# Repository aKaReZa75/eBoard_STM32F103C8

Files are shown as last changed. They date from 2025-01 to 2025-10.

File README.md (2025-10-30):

# STM32F103C8T6 Microcontroller

This repository involves designing, assembling, and testing an educational header board for the STM32F103C8 microcontroller, compatible with the Arduino UNO.

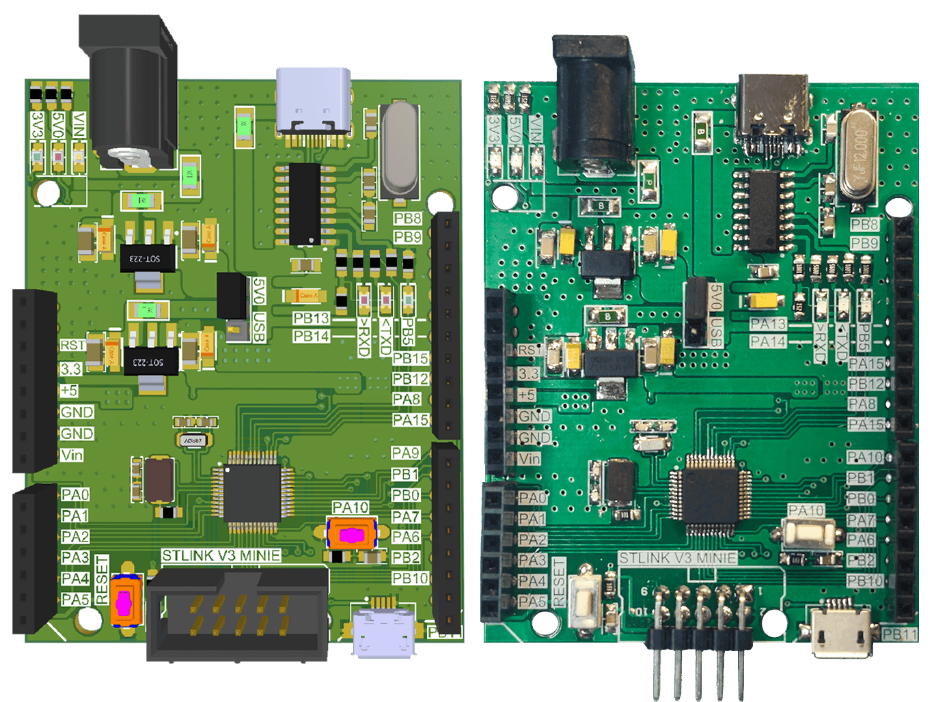
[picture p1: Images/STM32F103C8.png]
STM32F103C8 Shield


> [!IMPORTANT]
> Before sending the board files for PCB fabrication, **always make sure you are using the latest released version** of the project.
> Hardware issues or design flaws might exist in earlier versions and could be fixed in newer releases.
> To avoid costly mistakes and ensure the best performance, always refer to the **[Releases](../../releases)** section, where all known issues, updates, and version-specific notes are clearly documented.

## STM32F103C8T6 Pin Mapping Table 
| **Arduino Pin** | **STM32F103C8 Pin** | **Functionality** |
| :---: | :---: | :--- |
| A0 | PA0 | ADC-IN0 |
| A1 | PA1 | ADC-IN1 |
| A2 | PA2 | ADC-IN2 |
| A3 | PA3 | ADC-IN3 |
| A4 | PA4 | ADC-IN4 |
| A5 | PA5 | ADC-IN5 |
| D0 | PB11 | UART3-RX |
| D1 | PB10 | UART3-TX |
| D2 | PB2 | GPIO |
| D3 | PA6 | TIM3-CH1 PWM |
| D4 | PA7 | TIM3-CH2 PWM |
| D5 | PB0 | TIM3-CH3 PWM |
| D6 | PB1 | TIM3-CH4 PWM |
| D7 | PA9 | GPIO |
| D8 | PA15 | TIM2-CH1 ICP |
| D9 | PA8 | TIM1-CH1 PWM |
| D10 | PB12 | SPI2 (NSS) |
| D11 | PB15 | SPI2 (MOSI) |
| D12 | PB14 | SPI2 (MISO) |
| D13 | PB13 | SPI2 (SCK) |
| SDA | PB9 | I2C1 (SDA) |
| SCL | PB8 | I2C1 (SCL) |
| LED | PB5 | Built-in LED |
| KEY | PA10 | Built-in Key |
| CH340-RX | PB6 | UART1-TX (CH340)  |
| CH340-TX | PB7 | UART1-RX (CH340)  |

### **ADC (Analog-to-Digital Converter)**
| **Arduino Pin** | **STM32 Pin** | **ADC Channel** | 
| --- | --- | --- |
| A0 | PA0 | ADC_IN0 | 
| A1 | PA1 | ADC_IN1 | 
| A2 | PA2 | ADC_IN2 | 
| A3 | PA3 | ADC_IN3 | 
| A4 | PA4 | ADC_IN4 | 
| A5 | PA5 | ADC_IN5 | 

### **Timers / PWM Outputs**
| **Arduino Pin** | **STM32 Pin** | **PWM / Timer** |
| --- | --- | --- |
| D3 | PA6 | TIM3_CH1 (PWM)  |
| D4 | PA7 | TIM3_CH2 (PWM)  |
| D5 | PB0 | TIM3_CH3 (PWM)  |
| D6 | PB1 | TIM3_CH4 (PWM)  |
| D9 | PA8 | TIM1_CH1 (PWM)  |

| **Arduino Pin** | **STM32 Pin** | **Special Timer Function** |
| --- | --- | --- |
| D8 | PA15 | TIM2_CH1 (Input Capture) |

### **USART (Serial Communication)**
| **Function** | **Arduino Pin** | **STM32 Pin** | **USART Function** |
| --- | --- | --- | --- |
| UART3 RX | D0 | PB11 | USART3_RX |
| UART3 TX | D1 | PB10 | USART3_TX |
| CH340 RX (USB) | CH340-RX | PB6 | USART1_TX |
| CH340 TX (USB) | CH340-TX | PB7 | USART1_RX |

### **I2C Interface**
| **Arduino Pin** | **STM32 Pin** | **I2C Signal** |
| --- | --- | --- |
| SDA | PB9 | I2C1_SDA |
| SCL | PB8 | I2C1_SCL |

### **SPI Interface**
| **Arduino Pin** | **STM32 Pin** | **SPI Signal** |
| --- | --- | --- |
| D10 | PB12 | SPI2_NSS |
| D11 | PB15 | SPI2_MOSI |
| D12 | PB14 | SPI2_MISO |
| D13 | PB13 | SPI2_SCK |

### **Other / General Purpose**
| **Arduino Pin** | **STM32 Pin** | **Functionality** |
| --- | --- | --- |
| LED | PB5 | Onboard LED |
| KEY | PA10 | User Key |
| D2 | PB2 | GPIO/eInt |
| D7 | PA9 | GPIO/TIM1_CH2 |

---

<table>
  <tr>
  <td valign="top">
  
  > [!TIP]  
  > If you're looking to better understand how to navigate and use my GitHub repositories — including exploring their structure, downloading or cloning projects, submitting issues, and asking questions,  
  > everything you need is clearly explained in this video:  
  > [aKaReZa 95 - Programming, Git - PART B](https://youtu.be/zYiUItVFRqQ)  
  > Make sure to check it out!
  
  </td>
    <td width="360" valign="middle" style="padding: 0;">
      <a href="https://youtu.be/zYiUItVFRqQ">
       aKaReZa 95 - Programming, Git - PART B Thumbnail
      </a>
    </td>
  </td>
  </tr>

<tr>
  <td valign="top">
  
  > [!IMPORTANT]
  > Begin your embedded systems journey with clarity and purpose. This episode outlines a structured roadmap for mastering microcontrollers, communication protocols, hardware design, and project development.  
  > Learn how to choose your specialization, follow curated playlists, and engage effectively with the community—ideal for learners seeking a scalable, goal-driven path into embedded engineering.  
  > [aKaReZa 124 – Embedded Systems Roadmap](https://youtu.be/3QYfv7A7aMc)  
  > Watch it now to kickstart your journey!
  
  </td>
  <td width="360" valign="middle" style="padding: 0;">
    <a href="https://youtu.be/3QYfv7A7aMc">
      aKaReZa 124 – Embedded Systems Roadmap Thumbnail
    </a>
  </td>
</tr>

  <tr>
  <td colspan="3">

  > [!CAUTION]
  > It is absolutely critical that you carefully read every single word of this document, line by line, to ensure you don't miss any details. Nothing can be overlooked.
      
  </td>
  </tr>  
</table>

## Key Features
- **Core**: ARM Cortex-M3 32-bit RISC core.
- **Clock Speed**: Up to 72 MHz.
- **Flash Memory**: 64 KB of flash memory for program storage.
- **SRAM**: 20 KB of static RAM.
- **GPIO Pins**: 37 general-purpose I/O pins.
- **Communication Interfaces**:
  - **USART**: Up to 3 universal synchronous/asynchronous receivers/transmitters.
  - **SPI**: Up to 2 Serial Peripheral Interfaces.
  - **I2C**: Up to 2 Inter-Integrated Circuit interfaces.
  - **USB**: Full-speed USB 2.0 interface.
- **Timers**:
  - **Advanced-control Timers**: 1 x 16-bit.
  - **General-purpose Timers**: 3 x 16-bit.
  - **SysTick Timer**: 24-bit down counter.
- **ADC**: 2 x 12-bit Analog-to-Digital Converters with up to 10 channels.
- **DAC**: 2 x 12-bit Digital-to-Analog Converters.
- **DMA**: 7-channel Direct Memory Access controller.
- **Operating Voltage**: 2.0V to 3.6V.
- **Power Consumption**: Low-power modes for energy-efficient applications.

## Capabilities
- **High Performance**: ARM Cortex-M3 core delivers high efficiency and performance.
- **Rich Peripherals**: Integrated peripherals like USB, ADC, DAC, and timers make it suitable for complex applications.
- **Flexibility**: Supports a wide range of applications, from simple control systems to advanced IoT devices.
- **Ease of Development**: Extensive support from STM32CubeMX, HAL libraries, and third-party tools like ST-Link.
- **Community Support**: Large community and extensive documentation available.

## Applications
- **Embedded Systems**: Used in various embedded applications due to its robustness and flexibility.
- **IoT Devices**: Ideal for IoT applications with its low power consumption and communication interfaces.
- **Industrial Automation**: Suitable for industrial control systems and automation.
- **Consumer Electronics**: Found in various consumer electronic devices.
- **Robotics**: Commonly used in robotics for motor control and sensor interfacing.

## Development Tools
- **IDEs**: Keil MDK.
- **Programmers**: STLINK-V3MINIE.
- **Debuggers**: STLINK-V3MINIE, Serial debugging via UART, print (using SWO).

## Detailed Description
| Aspect | Description |
|---|---|
| PCB Design Software  | Altium  V24.2.2 |
| PCB Layers | 2-Layer FR4 |
| Microcontroller | STM32F103C8 |
| Pin Type | Arduino UNO |
| Converter IC | CH340 |
| USB Port | TYPE-C |

# 🔗 Resources
  Here you'll find a collection of useful links and documents related to the STM32 microcontroller and its applications.   
  These resources include datasheets, tutorials, and essential tools to get you started and guide you through.

> [!TIP]
> The resources are detailed in the sections below.  
> To access any of them, simply click on the corresponding blue link.

- [Altium Library](https://github.com/aKaReZa75/Altium-Library)  
  ---  
   All PCB designs across all repositories and projects are built using this Altium Designer component library. It contains a wide range of verified footprints, schematic symbols, and 3D models, ensuring consistency and accuracy in PCB designs. If you're working on a new PCB, using this library will save you time and minimize errors.

- [PCB & Electronics Design Training](https://github.com/aKaReZa75/PCB)  
  ---  
  This repository is dedicated to **learning PCB design and electronics from scratch**. It covers everything from circuit theory to practical PCB layout techniques, including routing strategies, best practices, and component placement. Whether you're a beginner or an experienced designer, this resource will help you **improve your PCB design skills and create professional-quality boards**.

- [Microcontroller Training](https://github.com/aKaReZa75/Microcontroller)  
  ---  
  This repository offers a comprehensive guide to learning **various microcontrollers** and how to interface them with different shields. You’ll find tutorials on **using and configuring shields**, along with hands-on projects to help you **get your microcontrollers up and running**. Whether you're working with **Arduino, STM32, ESP32**, or others, this resource will help you understand how to integrate these platforms effectively for your projects.

- [STM32 Microcontroller Training](https://github.com/aKaReZa75/STM32)  
  ---  
  This repository offers a **comprehensive guide to STM32 microcontroller programming**, focusing on the STM32F103C8T6. Explore **STM32 architecture, peripheral configuration, timers, interrupts, communication protocols (UART, SPI, I2C), and real-time applications** through practical examples and hands-on projects. Whether you're a beginner or an experienced developer, this resource will help you build a strong foundation and advance your skills in STM32 embedded development.

- [Shopping Link](./ShoppingLink.md)  
  ---
  This document provides links to trusted suppliers where you can purchase all the essential components for this project, ensuring quality and reliability.

## Project Videos

```plaintext
Educational Boards
   └── [aKaReZa 107 - eBoard, STM32F103C8]
       ├─ Design Review — Migrating from ATMEGA328 layout.
       ├─ Power Setup — Pin connections and safety.
       ├─ Oscillators — HSE and LSE integration.
       ├─ Boot Config — Pin modes and selection.
       ├─ Programmer — STLINK connection and setup.
       ├─ I/O Mapping — Practical pin assignments.
       └─ PCB Layout — Placement strategies for routing.
```

<table style="border-collapse: collapse;">
  <tr>
    <td valign="top" style="padding: 0 10px;">
      <h3 style="margin: 0;">
        <a href="https://youtu.be/Mtyp9QHlwoI">aKaReZa 107 – eBoard, STM32F103C8</a>
      </h3>
      <p style="margin: 8px 0 0;">
        Step-by-step guide to designing an educational STM32F103C8 board, covering power supply, oscillator setup, boot pin configurations, STLINK connection, I/O mapping, and PCB layout tips—ideal for mastering STM32 hardware design through hands-on learning.
      </p>
    </td>
    <td width="360" valign="top">
      <a href="https://youtu.be/Mtyp9QHlwoI">
        aKaReZa 107 – eBoard, STM32F103C8 Thumbnail
      </a>
    </td>
  </tr>

  <tr>
    <td valign="top" style="padding: 0 10px;">
      <h3 style="margin: 0;">
        <a href="https://youtu.be/Qt_0GZEKY6k">aKaReZa 111 – Repair, STM32F103C8 Soldering</a>
      </h3>
      <p style="margin: 8px 0 0;">
        Follow the complete soldering guide for the STM32F103C8 educational board, including power input setup, voltage regulator testing, microcontroller soldering, USB communication via CH340, THT connector mounting, and final board verification.
      </p>
    </td>
    <td width="360" valign="top">
      <a href="https://youtu.be/Qt_0GZEKY6k">
        aKaReZa 111 – Repair, STM32F103C8 Soldering Thumbnail
      </a>
    </td>
  </tr>
  
</table>

# 💻 How to Use Git and GitHub
To access the repository files and save them on your computer, there are two methods available:
1. **Using Git Bash and Cloning the Repository**
   - This method is more suitable for advanced users and those familiar with command-line tools.
   - By using this method, you can easily receive updates for the repository.

2. **Downloading the Repository as a ZIP file**
   - This method is simpler and suitable for users who are not comfortable with command-line tools.
   - Note that with this method, you will not automatically receive updates for the repository and will need to manually download any new updates.

## Clone using the URL.
First, open **Git Bash** :
-  Open the folder in **File Explorer** where you want the library to be stored.
-  **Right-click** inside the folder and select the option **"Open Git Bash here"** to open **Git Bash** in that directory.

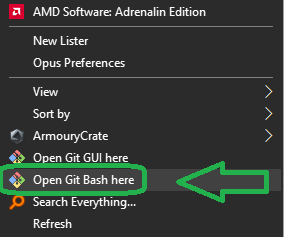
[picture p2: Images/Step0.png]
open Git Bash


> [!NOTE] 
> If you do not see the "Open Git Bash here" option, it means that Git is not installed on your system.  
> You can download and install Git from [this link](https://git-scm.com/downloads).  
> For a tutorial on how to install and use Git, check out [this video](https://youtu.be/BsykgHpmUt8).
  
-  Once **Git Bash** is open, run the following command to clone the repository:

 ```bash
git clone https://github.com/aKaReZa75/eBoard_STM32F103C8.git
```
- You can copy the above command by either:
- Clicking on the **Copy** button on the right of the command.
- Or select the command text manually and press **Ctrl + C** to copy.
- To paste the command into your **Git Bash** terminal, use **Shift + Insert**.

Clone the Repository

- Then, press Enter to start the cloning operation and wait for the success message to appear.

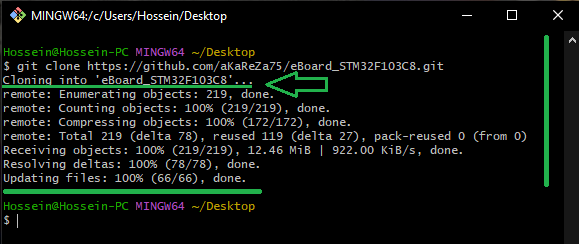
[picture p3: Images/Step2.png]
Open the Library File


> [!IMPORTANT]
> Please keep in mind that the numbers displayed in the image might vary when you perform the same actions.  
> This is because repositories are continuously being updated and expanded. Nevertheless, the overall process remains unchanged.

> [!NOTE]
> Advantage of Cloning the Repository:  
> - **Receiving Updates:** By cloning the repository, you can easily and automatically receive new updates.  
> - **Version Control:** Using Git allows you to track changes and revert to previous versions.  
> - **Team Collaboration:** If you are working on a project with a team, you can easily sync changes from team members and collaborate more efficiently.  

## Download Zip
If you prefer not to use Git Bash or the command line, you can download the repository directly from GitHub as a ZIP file.  
Follow these steps:  
1. Navigate to the GitHub repository page and Locate the Code button:
   - On the main page of the repository, you will see a green Code button near the top right corner.

2. Download the repository:
   - Click the Code button to open a dropdown menu.
   - Select Download ZIP from the menu.

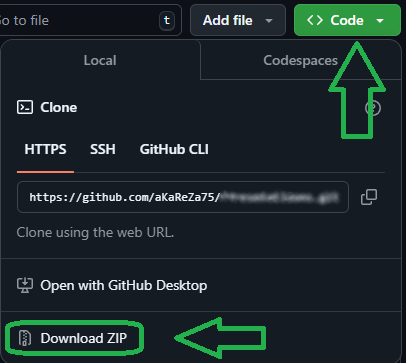
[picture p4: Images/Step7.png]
Download Zip
    

3. Save the ZIP file:
   - Choose a location on your computer to save the ZIP file and click Save.

4. Extract the ZIP file:
   - Navigate to the folder where you saved the ZIP file.
   - Right-click on the ZIP file and select Extract All... (Windows) or use your preferred extraction tool.
   - Choose a destination folder and extract the contents.

5. Access the repository:
   - Once extracted, you can access the repository files in the destination folder.

> [!IMPORTANT]
> - No Updates: Keep in mind that downloading the repository as a ZIP file does not allow you to receive updates.    
>   If the repository is updated, you will need to download it again manually.  
> - Ease of Use: This method is simpler and suitable for users who are not comfortable with Git or command-line tools.

# 📝 How to Ask Questions
If you have any questions or issues, you can raise them through the **"Issues"** section of this repository. Here's how you can do it:  

1. Navigate to the **"Issues"** tab at the top of the repository page.  

  Issues

2. Click on the **"New Issue"** button.  
   
  New Issue

3. In the **Title** field, write a short summary of your issue or question.  

4. In the "Description" field, detail your question or issue as thoroughly as possible. You can use text formatting, attach files, and assign the issue to someone if needed. You can also use text formatting (like bullet points or code snippets) for better readability.  

5. Optionally, you can add **labels**, **type**, **projects**, or **milestones** to your issue for better categorization.  

6. Click on the **"Submit new issue"** button to post your question or issue.
   
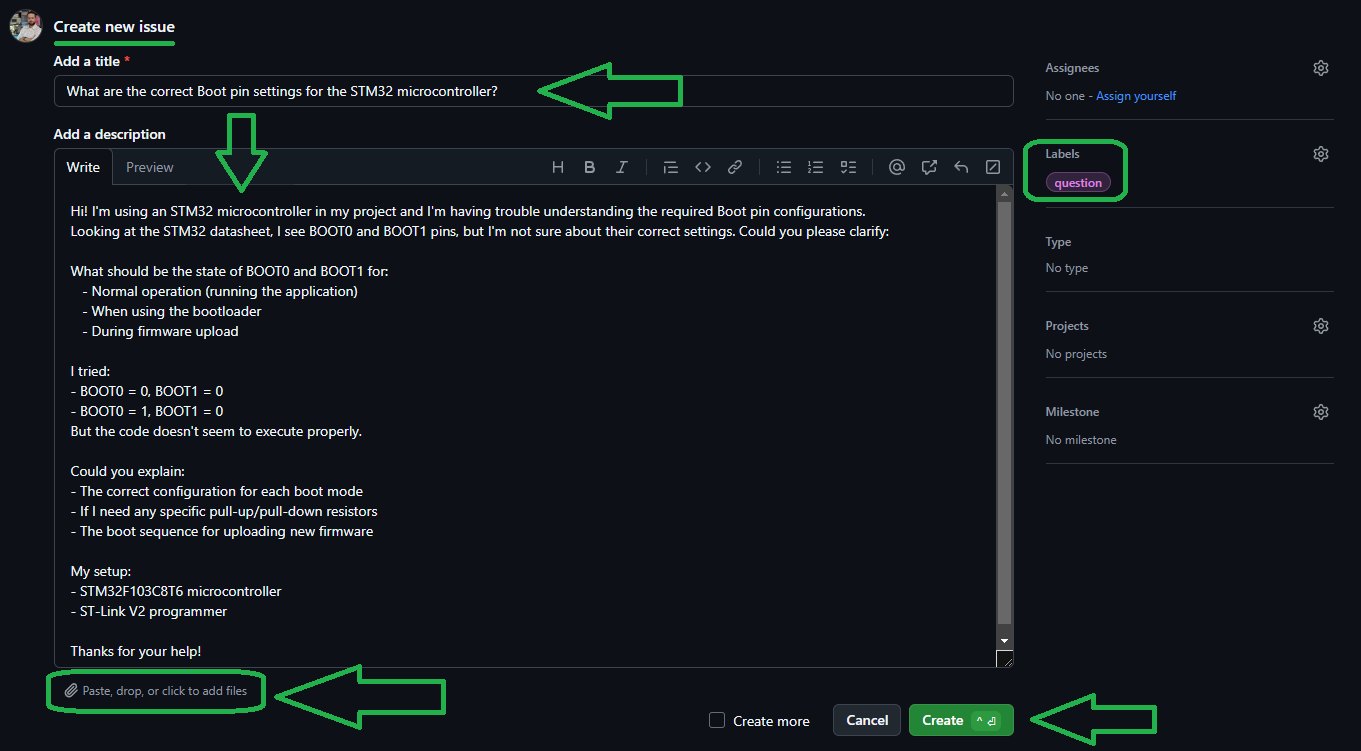
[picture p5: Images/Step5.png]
Submeet New Issue
  

I will review and respond to your issue as soon as possible. Your participation helps improve the repository for everyone!  

> [!TIP]
> - Before creating a new issue, please check the **"Closed"** section to see if your question has already been answered.  
>   Closed section  
> - Write your question clearly and respectfully to ensure a faster and better response.  
> - While the examples provided above are in English, feel free to ask your questions in **Persian (فارسی)** as well.  
> - There is no difference in how they will be handled!  

> [!NOTE]
> Pages and interfaces may change over time, but the steps to create an issue generally remain the same.

# 🤝 Contributing to the Repository
To contribute to this repository, please follow these steps:
1. **Fork the Repository**  
2. **Clone the Forked Repository**  
3. **Create a New Branch**  
4. **Make Your Changes**  
5. **Commit Your Changes**  
6. **Push Your Changes to Your Forked Repository**  
7. **Submit a Pull Request (PR)**  

> [!NOTE]
> Please ensure your pull request includes a clear description of the changes you’ve made.
> Once submitted, I will review your contribution and provide feedback if necessary.

# 🌟 Support Me
If you found this repository useful:
- Subscribe to my [YouTube Channel](https://www.youtube.com/@aKaReZa75).
- Share this repository with others.
- Give this repository and my other repositories a star.
- Follow my [GitHub account](https://github.com/aKaReZa75).

# 📜 License
This project is licensed under the GPL-3.0 License. This license grants you the freedom to use, modify, and distribute the project as long as you:
- Credit the original authors: Give proper attribution to the original creators.
- Disclose source code: If you distribute a modified version, you must make the source code available under the same GPL license.
- Maintain the same license: When you distribute derivative works, they must be licensed under the GPL-3.0 too.
- Feel free to use it in your projects, but make sure to comply with the terms of this license.
  
# ✉️ Contact Me
Feel free to reach out to me through any of the following platforms:
- 📧 [Email: aKaReZa75@gmail.com](mailto:aKaReZa75@gmail.com)
- 🎥 [YouTube: @aKaReZa75](https://www.youtube.com/@aKaReZa75)
- 💼 [LinkedIn: @akareza75](https://www.linkedin.com/in/akareza75)

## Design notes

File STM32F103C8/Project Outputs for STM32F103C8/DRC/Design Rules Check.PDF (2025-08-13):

### Design Rules Verification Report

Filename : E:\aKaReZa\#gitHub\eBoard_STM32F103C8\STM32F103C8\PCB.PcbDoc | Warnings 0

### Rule Violations 0 Waived Violations 6

Warnings
Total | 0

Rule Violations
Clearance Constraint (Gap=0.2mm) (All),(All) | 0
Clearance Constraint (Gap=0.25mm) (All),(InPolygon) | 0
Short-Circuit Constraint (Allowed=No) (All),(All) | 0
Un-Routed Net Constraint ( (All) ) | 0
Modified Polygon (Allow modified: No), (Allow shelved: No) | 0
Width Constraint (Min=0.2mm) (Max=10mm) (Preferred=0.2mm) (All) | 0
Routing Layers(All) | 0
Routing Via (MinHoleWidth=0.4mm) (MaxHoleWidth=3mm) (PreferredHoleWidth=0.4mm) (MinWidth=0.7mm) | 0
Differential Pairs Uncoupled Length using the Gap Constraints (Min=0.254mm) (Max=0.254mm) (Prefered=0.254mm) | 0
Power Plane Connect Rule(Relief Connect )(Expansion=0.508mm) (Conductor Width=0.254mm) (Air Gap=0.254mm) | 0
Minimum Annular Ring (Minimum=0.15mm) (All) | 0
Acute Angle Constraint [Tracks Only] (Minimum=60.000) (All) | 0
Hole Size Constraint (Min=0.4mm) (Max=10mm) (All) | 0
Hole To Hole Clearance (Gap=0.3mm) (All),(All) | 0
Minimum Solder Mask Sliver (Gap=0.01mm) (All),(All) | 0
Silk To Solder Mask (Clearance=0.01mm) (IsPad),(All) | 0
Net Antennae (Tolerance=0mm) (All) | 0
Board Clearance Constraint (Gap=0mm) (All) | 0
Height Constraint (Min=0mm) (Max=25.4mm) (Prefered=12.7mm) (All) | 0
Total | 0

Waived Violations
Minimum Annular Ring (Minimum=0.15mm) (All) | 6
Total | 6

Minimum Annular Ring (Minimum=0.15mm) (All)
Minimum Annular Ring: (No Ring) Pad P2-H1(2.667mm,54.737mm) on Multi-Layer (Annular Ring missing on Top Layer)Waived by aKaReZa at
Minimum Annular Ring: (No Ring) Pad P2-H2(7.747mm,2.667mm) on Multi-Layer (Annular Ring missing on Top Layer)Waived by aKaReZa at Minimum Annular Ring: (No Ring) Pad P2-H3(35.687mm,2.667mm) on Multi-Layer (Annular Ring missing on Top Layer)Waived by aKaReZa at Minimum Annular Ring: (No Ring) Pad P2-H4(50.927mm,53.467mm) on Multi-Layer (Annular Ring missing on Top Layer)Waived by aKaReZa at Minimum Annular Ring: (No Ring) Via (41.675mm,3.674mm) from Top Layer to Bottom Layer (Annular Ring missing on Top Layer)Waived by its ok at Minimum Annular Ring: (No Ring) Via (45.675mm,3.674mm) from Top Layer to Bottom Layer (Annular Ring missing on Top Layer)Waived by its ok at

Reference point outside the component area: Small Component J2-Female (14.224mm,72.771mm) on Top Layer

Micro-Segment: Region (0 hole(s)) Top Layer P1(16.51mm,51.689mm) P2(16.51mm,51.689mm)

Micro-Segment: Region (0 hole(s)) Top Layer P1(16.51mm,49.403mm) P2(16.51mm,49.403mm)

Self-intersection: Region (0 hole(s)) Top Layer (9.273mm,29.045mm)

Wednesday 13 Aug 2025 1:45:30 PM | Page 1 of 1

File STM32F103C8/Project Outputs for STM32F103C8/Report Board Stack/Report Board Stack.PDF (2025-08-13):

# Board Stack Report

Stack Up | Layer Stack
Layer | Board Layer Stack | Name | Material | Thickness Constant Dk | | | Coverlay expansion | Orientation | Copper Orientation
1 | | Top Overlay | | 0mm
2 | | Top Solder | Solder Resist | 0.01016mm | 3.5 | 3.5 0mm
3 | | Top Layer | | 0.03556mm | | | | BodyUp | Above
4 | | Dielectric 1 | FR-4 | 1.5mm | 4.8 | 4.8
5 | | Bottom Layer | | 0.03556mm | | | | BodyDown | Below
6 | | Bottom Solder | Solder Resist | 0.01016mm | 3.5 | 3.5 0mm
7 | | Bottom Overlay | | 0mm
| Height : 1.59144mm

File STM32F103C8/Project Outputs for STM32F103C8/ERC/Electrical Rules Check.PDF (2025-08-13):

### Electrical Rules Check Report

Class | Document | Message Successful Compile for STM32F103C8.PrjPcb
Wednesday 13 Aug 2025 1:45:31 PM | Page 1 of 1

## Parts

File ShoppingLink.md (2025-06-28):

# 📦 Components Purchase Links
This section provides a comprehensive list of components required for the "STM32F103C8 Board" project.
Each item includes direct purchase links from reliable Iranian electronics suppliers, with recommended quantities for both essential needs and future prototyping.

## Capacitor
- [ ] [**Cap_0603_18p**](https://lionelectronic.ir/products/1900-0603CG180J500NT) Quantity: 2, Prefer: 25, Supplier: LionElectronic **(Instead of: Cap_0603_18.5p)**
- [ ] [**Cap_0603_33p**](https://lionelectronic.ir/products/3759-GRM1885C1H330FA01D) Quantity: 2, Prefer: 25, Supplier: LionElectronic
- [ ] [**Cap_0805_22p**](https://lionelectronic.ir/products/1950-TCC0805COG220J500BT) Quantity: 2, Prefer: 25, Supplier: LionElectronic
- [ ] [**Cap_0805_10n**](https://lionelectronic.ir/products/1973-0805B103K500NT) Quantity: 1, Prefer: 25, Supplier: LionElectronic
- [ ] [**Cap_0805_100n**](https://lionelectronic.ir/products/2791-CL21B104KBCNNNC) Quantity: 8, Prefer: 25, Supplier: LionElectronic
- [ ] [**Cap_1206_100n**](https://lionelectronic.ir/products/5156-C3216NP01H104J160AA) Quantity: 4, Prefer: 25, Supplier: LionElectronic
- [ ] [**Cap_Tantal_10u_10V_A**](https://lionelectronic.ir/products/2046-TAJA106K010RNJ) Quantity: 2, Prefer: 10, Supplier: LionElectronic **(Instead of: Cap_Tantal_10u_6.3V_A)**
- [ ] [**Cap_Tantal_10u_16V_A**](https://lionelectronic.ir/products/2047-TAJA106K016RNJ) Quantity: 2, Prefer: 5, Supplier: LionElectronic 
- [ ] [**Cap_Tantal_22u_6.3V_A**](https://lionelectronic.ir/products/2051-TAJA226M006RNJ) Quantity: 2, Prefer: 5, Supplier: LionElectronic 

## Connector
- [ ] [**Power_Jack**](https://lionelectronic.ir/products/4704-DC005) Quantity: 1, Prefer: 10, Supplier: LionElectronic  
- [ ] [**Con_BoxHeadr_2x5**](https://roboeq.ir/products/detail/1504018/%D8%A8%D8%A7%DA%A9%D8%B3-%D9%87%D8%AF%D8%B1-5-2-BOX-HEADER-%D8%B5%D8%A7%D9%81/) Quantity: 1, Prefer: 5, Supplier: RoboEQ  
- [ ] [**Con_IDC_2x5**](https://roboeq.ir/products/detail/1504001/%D8%A2%DB%8C-%D8%AF%DB%8C-%D8%B3%DB%8C-IDC-2-5/) Quantity: 1, Prefer: 5, Supplier: RoboEQ  
- [ ] [**Flat Cable**](https://roboeq.ir/products/detail/1301002/%DA%A9%D8%A7%D8%A8%D9%84-20-%D8%B1%D8%B4%D8%AA%D9%87-%D9%81%D9%84%D8%AA/) Quantity: 0.2, Prefer: 1, Supplier: RoboEQ  
- [ ] [**Male_PinHeader**](https://lionelectronic.ir/products/5356-PLS-2.54-1X40GF) Quantity: 0.1, Prefer: 1, Supplier: LionElectronic  
- [ ] [**Female_PinHeader**](https://lionelectronic.ir/products/5360-PBS-2.54-1X40GF) Quantity: 1, Prefer: 2, Supplier: LionElectronic  
- [ ] [**USB_Type_C_12**](https://ickala.com/usb-onboard/29448-usb-smd-onboard.html) Quantity: 1, Prefer: 2, Supplier: ICkala
- [ ] [**USB_Type_Micro**](https://lionelectronic.ir/products/4129-MicroQTJ) Quantity: 1, Prefer: 2, Supplier: LionElectronic 

## Integrated Circuit
- [ ] [**IC_STM32F103C8**](https://lionelectronic.ir/products/267-STM32F103C8T6) Quantity: 1, Prefer: 3, Supplier: LionElectronic   
- [ ] [**Reg_AMS1117-5**](https://lionelectronic.ir/products/2189-AMS1117-5.0) Quantity: 1, Prefer: 3, Supplier: LionElectronic  
- [ ] [**Reg_AMS1117-3.3**](https://lionelectronic.ir/products/868-AMS1117-3.3) Quantity: 1, Prefer: 3, Supplier: LionElectronic  
- [ ] [**IC_CH340G**](https://lionelectronic.ir/products/3547-CH340G) Quantity: 1, Prefer: 2, Supplier: LionElectronic  

## Inductor
- [ ] [**Ind_0805_100u**](https://lionelectronic.ir/products/2146-EBLS201212-101K) Quantity: 1, Prefer: 5, Supplier: LionElectronic

## Other
- [ ] [**Fuse_1206_0.5A**](https://lionelectronic.ir/products/1891-JFC1206-0500FS-63V-0.5A) Quantity: 3, Prefer: 10, Supplier: LionElectronic  
- [ ] [**Fuse_1206_3A**](https://lionelectronic.ir/products/1894-JFC1206-1300FS-63V-3A) Quantity: 1, Prefer: 5, Supplier: LionElectronic
- [ ] [**Crystal 32.768KHz**](https://lionelectronic.ir/products/4290-XKXGI-SUA-32.768K) Quantity: 1, Prefer: 5, Supplier: LionElectronic
- [ ] [**Crystal 8MHz**](https://lionelectronic.ir/products/2158-XTAL-8MHZ%28YSX530GA%29) Quantity: 1, Prefer: 5, Supplier: LionElectronic
- [ ] [**Crystal 12MHz**](https://lionelectronic.ir/products/2096-XTAL-12MHZ%28HC-49SMD%29) Quantity: 1, Prefer: 5, Supplier: LionElectronic
- [ ] [**Jumper**](https://ickala.com/pin-header-jumper/26295-jumper2pin-%D9%82%D8%B1%D9%85%D8%B2.html) Quantity: 1, Prefer: 10, Supplier: ICKala

## Resistor
- [ ] [**Res_0805_0b**](https://lionelectronic.ir/products/1536-SER0805J0R) Quantity: 2, Prefer: 25, Supplier: LionElectronic
- [ ] [**Res_0805_220b**](https://lionelectronic.ir/products/1565-SER0805J220R) Quantity: 1, Prefer: 25, Supplier: LionElectronic  
- [ ] [**Res_0805_390b**](https://lionelectronic.ir/products/1416-0805W8F3900T5E) Quantity: 1, Prefer: 25, Supplier: LionElectronic
- [ ] [**Res_0805_680b**](https://lionelectronic.ir/products/1571-0805W8J0681T5E) Quantity: 3, Prefer: 25, Supplier: LionElectronic
- [ ] [**Res_0805_1K**](https://lionelectronic.ir/products/1573-RS-05K102JT) Quantity: 3, Prefer: 25, Supplier: LionElectronic  
- [ ] [**Res_0805_1.8K**](https://lionelectronic.ir/products/1576-0805W8J0182T5E) Quantity: 2, Prefer: 25, Supplier: LionElectronic
- [ ] [**Res_0805_4.7K**](https://lionelectronic.ir/products/1581-SER0805J4K7) Quantity: 2, Prefer: 25, Supplier: LionElectronic 
- [ ] [**Res_0805_10K**](https://lionelectronic.ir/products/1585-SCR0805J10K) Quantity: 2, Prefer: 25, Supplier: LionElectronic

## Semiconductore
- [ ] [**LED_0805_Red**](https://lionelectronic.ir/products/2207-XL-2012SURC) Quantity: 3, Prefer: 10, Supplier: LionElectronic  
- [ ] [**LED_0805_Yellow**](https://lionelectronic.ir/products/3267-XL-2012UYC) Quantity: 1, Prefer: 10, Supplier: LionElectronic  
- [ ] [**LED_0805_Green**](https://lionelectronic.ir/products/3265-XL-2012SYGC) Quantity: 2, Prefer: 10, Supplier: LionElectronic

## Switch
- [ ] [**SW_PushButton-6-3.7-2.5**](https://lionelectronic.ir/products/4165-TS365TP) Quantity: 2, Prefer: 5, Supplier: LionElectronic

# 🌟 Support Me
If you found this repository useful:
- Subscribe to my [YouTube Channel](https://www.youtube.com/@aKaReZa75).
- Share this repository with others.
- Give this repository and my other repositories a star.
- Follow my [GitHub account](https://github.com/aKaReZa75).

# ✉️ Contact Me
Feel free to reach out to me through any of the following platforms:
- 📧 [Email: aKaReZa75@gmail.com](mailto:aKaReZa75@gmail.com)
- 🎥 [YouTube: @aKaReZa75](https://www.youtube.com/@aKaReZa75)
- 💼 [LinkedIn: @akareza75](https://www.linkedin.com/in/akareza75)

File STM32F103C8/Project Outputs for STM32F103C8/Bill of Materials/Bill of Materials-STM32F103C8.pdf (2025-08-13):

Altium Limited Confidential | 8/13/2025 | Page 1

# Bill of Materials

Title: Bill of Materials for Project [STM32F103C8.PrjPcb] (No PCB Document Selected) Project: STM32F103C8 EB
Company github.com/aKaReZa75
Variant: None
Revision: 1.0.1
Inflow | LibRef | Footprint | Value | Rating | Package | Type | Description | Comment | Quantity
inflow? | Cap_Multi_SMD | CAP 0603/1608 | 18p | Rating? | 0603 | Type? | Bipolar ceramic capacitor SMD | 18p | 2
inflow? | Cap_Multi_SMD | CAP 0603/1608 | 33p | Rating? | 0603 | Type? | Bipolar ceramic capacitor SMD | 33p | 2
inflow? | Cap_Multi_SMD_100nF_0805 | CAP 0805/2012 | 100n | 50V | 0805 | MultiLayer | Bipolar ceramic capacitor SMD | 100n | 8
inflow? | Cap_Multi_SMD_100nF_1206 | CAP 1206/3216 | 100n | 50V | 1206 | MultiLayer | Bipolar ceramic capacitor SMD | 100n | 4
inflow? | Cap_Multi_SMD_0805 | CAP 0805/2012 | 10n | Rating? | 0805 | MultiLayer | Bipolar ceramic capacitor SMD | 10n | 1
inflow? | Cap_Multi_SMD_0805 | CAP 0805/2012 | 22p | Rating? | 0805 | MultiLayer | Bipolar ceramic capacitor SMD | 22p | 2
inflow? | Cap_Tantalum | SMT_C_Tantalum_A | 10u | 6.3V, 16V | Package? | Tantalum | Tantalum Capacitor,TAJ Series-SMD | 10u | 4
inflow? | Cap_Tantalum | SMT_C_Tantalum_A | 22u | 6.3V | Package? | Tantalum | Tantalum Capacitor,TAJ Series-SMD | 22u | 2
inflow? | Con_Arduino_UNO_Con | ARDUINO_UNO_CONNECTOR UNO | | Rating? | Package? | Type? | Arduino UNO Connector | UNO | 1
6127 | Con_Power_Jack | Power Jack BIG | Female | Rating? | Package? | Type? | Power Jack | Female | 1
7119 | Con_Prog_STLinkV3_SWD | IDC2.54-10PIN | STLinkV3- | Rating? | Package? | SWD | STLINK-V3MINIE debugger/ | STLinkV3-minie | 1
inflow? | Con_USB2_Micro | USB_Micro_Standard | Micro | Rating? | Package? | Type? | USB micro female | Micro | 1
inflow? | Con_USB_C | HRO_TYPE-C-31-M-12 - | 12b | Rating? | SMD | C | USB C Female Connector | 12b | 1
inflow? | IC_Converter_CH340G | SO16_M | CH340G | Rating? | SO-16 | USB to TTL | TTL To USB Chip | CH340G | 1
inflow? | IC_MCU_STM32F103C8T6 | LQFP48_N | STM32F103 | CORTEX-M3LQFP48 | | Microcontroll | 32-Bit mircrocontroller | STM32F103C8T6 | 1
5217 | IC_Reg_AMS1117_3.3 | SOT223_M | 3.3V | 1A | SOT223 | LDO | 1'A Positive voltage regulator | 3.3V | 1
5217 | IC_Reg_AMS1117_3.3 | SOT223_M | 5V | 1A | SOT223 | LDO | 1'A Positive voltage regulator | 5V | 1
inflow? | Ind_SMD_0805 | IND0805 | 100u | Rating? | 0805 | SMD | Inductor | 100u | 1
inflow? | Other_Elec_Fuse_SMD | 1206_F | 0.5A | Rating? | 1206 | Fast | Short circiut protection | 0.5A | 3
inflow? | Other_Elec_Fuse_SMD | 1206_F | 3A | Rating? | 1206 | Fast | Short circiut protection | 3A | 1
inflow? | Other_Elec_Jumper_0805 | RESC2012M (0805) | Jumper | Rating? | 0805 | Type? | Jumper Component | Jumper | 1
inflow? | Other_Elec_Xtal_8MHZ_SMD | XTL_2_5032 | 8MHz | 10ppm | 5032 | Crystal | Crystal Oscillator | 8MHz | 1
inflow? | Other_Elec_Xtal_32.768K_SMD | XTL_2_3215 | 32.768KHz | 20ppm | 3215 | Crystal | Crystal Oscillator | 32.768KHz | 1
inflow? | Other_Elec_Xtal_SMD | Crystal SMD | 12M | Rating? | SMD | Quartz | Crystal Oscillator | 12M | 1
inflow? | Res_SMD_0805 | RES 0805 (2012X06L) | 1K | 0.125W | 0805 | 10% | Resistor | 1K | 3
inflow? | Res_SMD_0805 | RES 0805 (2012X06L) | 1.8K | 0.125W | 0805 | 10% | Resistor | 1.8K | 2
inflow? | Res_SMD_0805 | RES 0805 (2012X06L) | 4.7K | 0.125W | 0805 | 10% | Resistor | 4.7K | 2
inflow? | Res_SMD_0805 | RES 0805 (2012X06L) | 10K | 0.125W | 0805 | 10% | Resistor | 10K | 2
inflow? | Res_SMD_0805 | RES 0805 (2012X06L) | 220b | 0.125W | 0805 | 10% | Resistor | 220b | 1
inflow? | Res_SMD_0805 | RES 0805 (2012X06L) | 390b | 0.125W | 0805 | 10% | Resistor | 390b | 1
inflow? | Res_SMD_0805 | RES 0805 (2012X06L) | 680b | 0.125W | 0805 | 10% | Resistor | 680b | 3
inflow? | Semi_LED_SMD | LED 0805/2012 GREEN | Green | Rating? | Package? | LED | LED | Green | 2
inflow? | Semi_LED_SMD | LED 0805/2012 RED | Red | Rating? | Package? | LED | LED | Red | 3
inflow? | Semi_LED_SMD | LED 0805/2012 YELLOW | Yellow | Rating? | Package? | LED | LED | Yellow | 1
5145 | SW_Other_JSelector_Dip | jumper selector | 0b | Rating? | Dip | Selector | Jumper Selector | 0b | 1
8260 | SW_PushButton_2_SMD | SW_PB_SMD_2PIN_SPST_6X | PB | 2b | SMD | Vertical | SMT Tactile ‎Switch | PB | 2
Approved Notes | | | | | | | | | 66

8/13/2025 1:47 PM
Hossein Bagheri

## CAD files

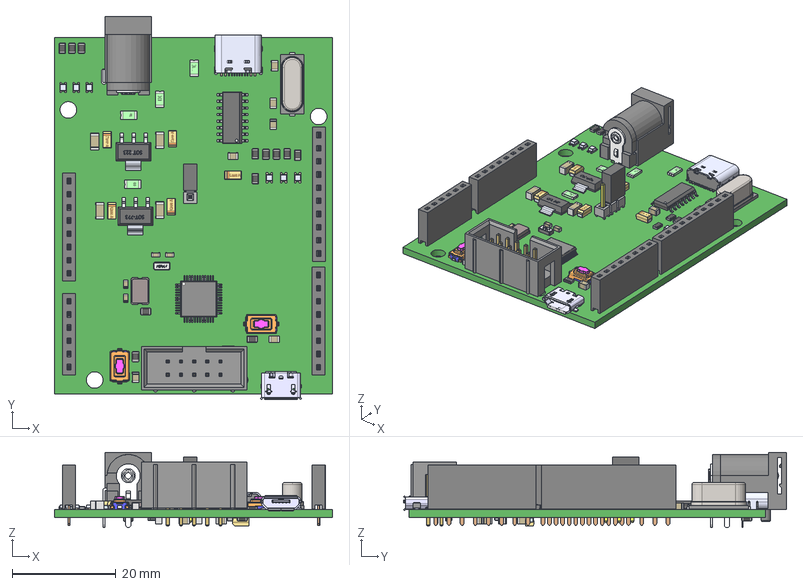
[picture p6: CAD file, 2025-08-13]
STM32F103C8/Project Outputs for STM32F103C8/Export STEP/PCB.step
53.6 x 73.9 x 14.5 mm
SKQYPA_43452 x 2
0805 cap x 11
User Library-Cap-Tantalum-Case-A-3216-18 x 6
User Library-Micro USB
User Library-ABS07_ABS07 Body_2
User Library-ABS07_ABS07 Body2_2
User Library-ABS07_ABS07 Beschriftung_2
User Library-ABS07_ABS07 Pads_2
0603 cap x 4
User Library-IDC Socket Male 10pin Straight THT Goldplated 2_54mm
User Library-ABM3_BodyBase
User Library-ABM3_TopCap
User Library-ABM3_Pocket001
User Library-ABM3_Pocket
User Library-HC49_SMD
User Library-QFP-48
PIN_SOT-223_2_1 x 6
SOT-223_1 x 2
PIN_SOT-223_1 x 2
Header3
Extruded
TYPE-C-31-M-12
User Library-FUSE-1206 x 4
LED 0805 Base RED x 3
LED 0805 Lens RED x 3
LED 0805 Lens GREEN x 2
LED 0805 Base GREEN x 2
1206 cap x 4
User Library-SO-16N__X2_041A043E0440043F04430441_X0_
User Library-SO-16N__X2_041C04350442043A0430_X0_
User Library-SO-16N__X2_041D043E0436043A0430_X0_ x 8
6130xx11821_PIN x 32
SW3dPS-PowerJack-2.5x5.7mm
LED 0805 Lens YELLOW
LED 0805 Base YELLOW

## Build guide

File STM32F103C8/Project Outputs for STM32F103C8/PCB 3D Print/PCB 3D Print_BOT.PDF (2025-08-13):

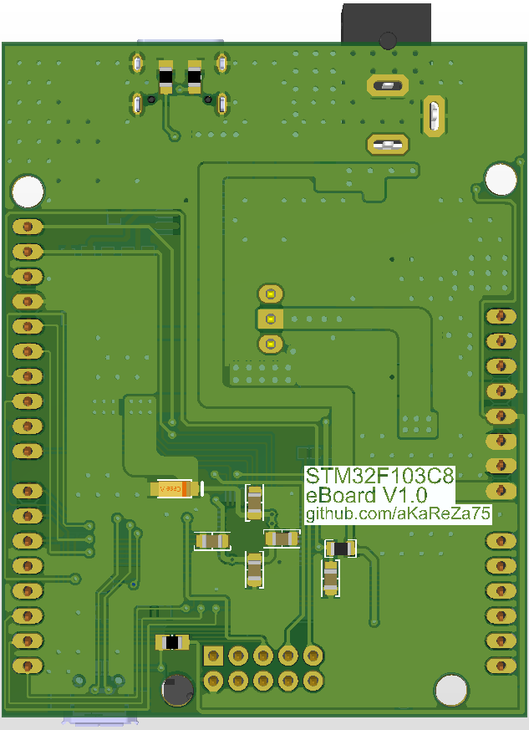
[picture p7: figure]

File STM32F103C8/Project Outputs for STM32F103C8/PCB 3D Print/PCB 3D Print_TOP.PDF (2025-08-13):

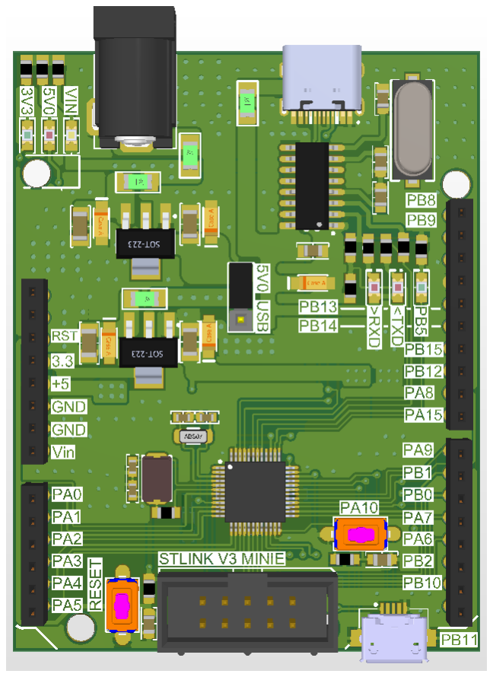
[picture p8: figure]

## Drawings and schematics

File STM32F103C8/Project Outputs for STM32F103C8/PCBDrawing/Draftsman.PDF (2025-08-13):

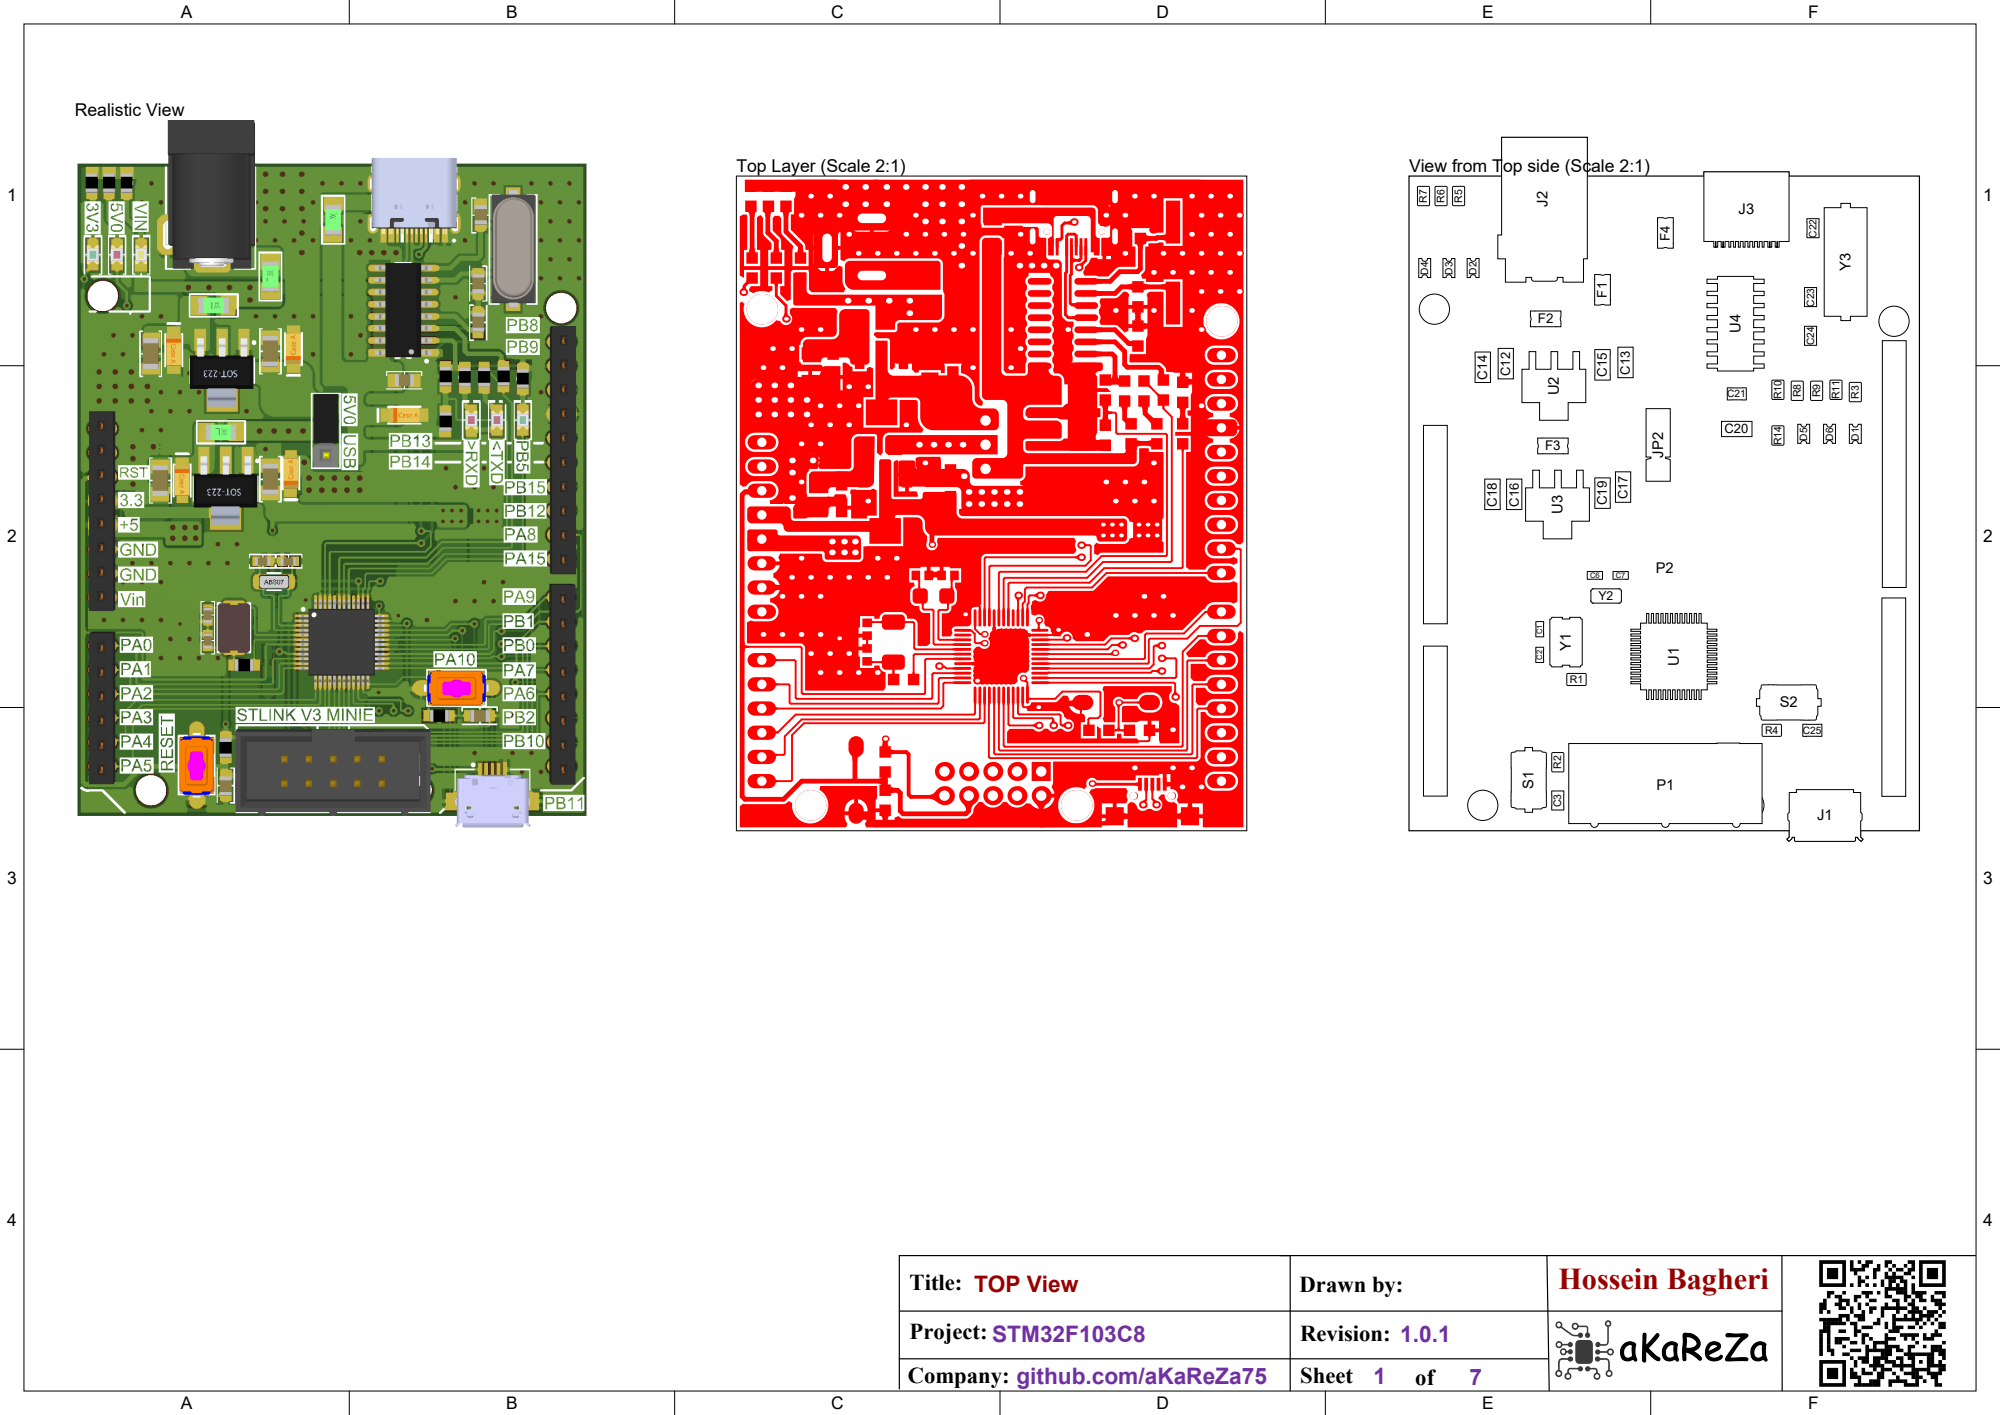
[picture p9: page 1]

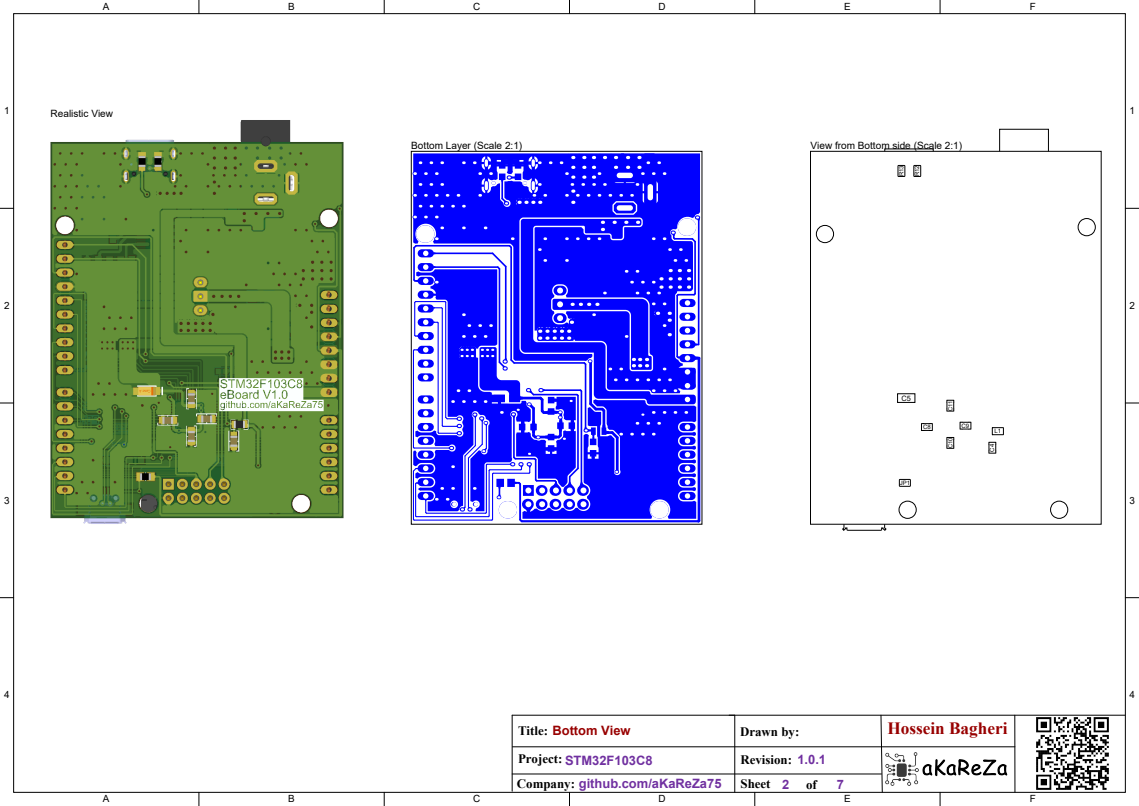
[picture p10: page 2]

View from Bottom side (Scale 2:1)

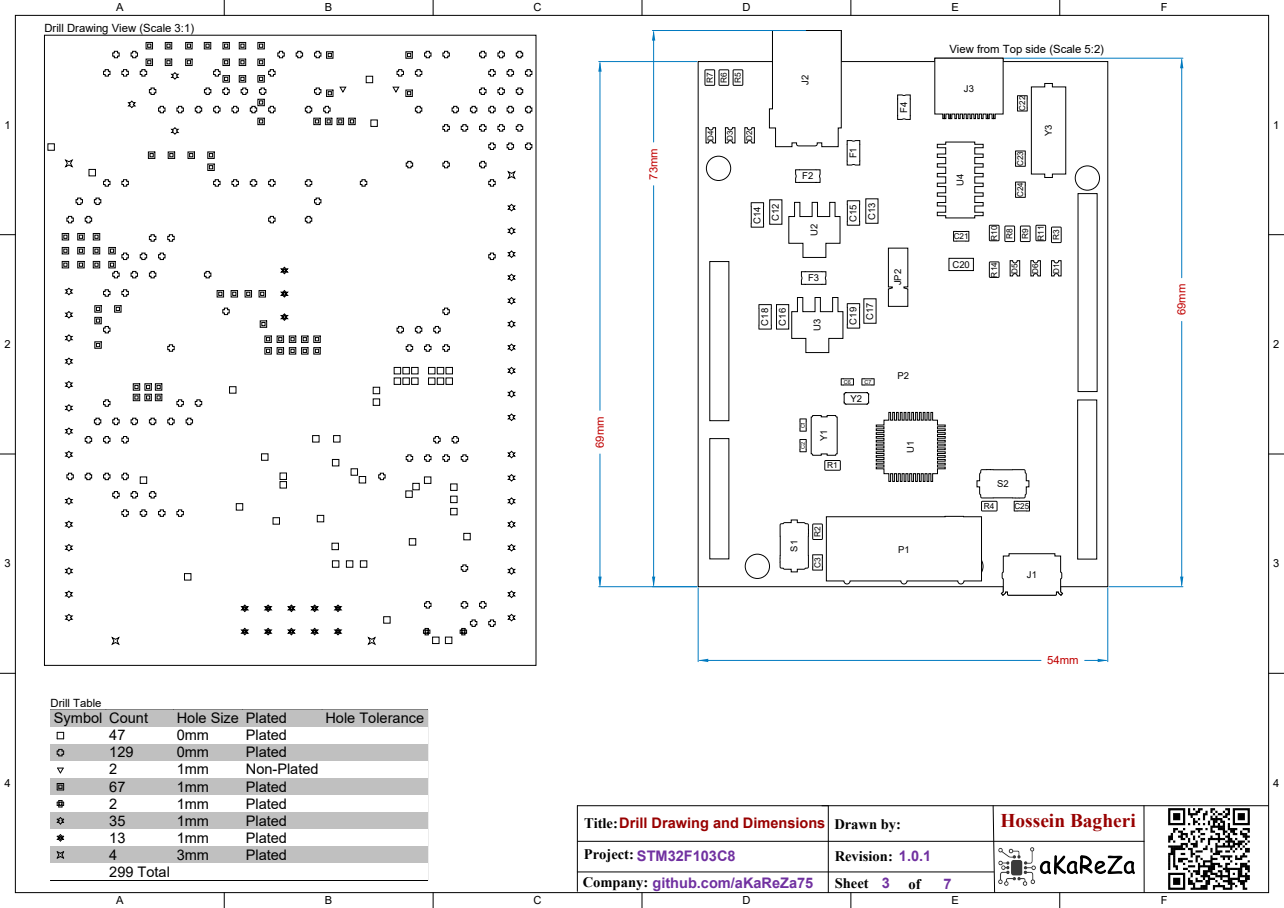
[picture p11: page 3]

Drill Drawing View (Scale 3:1)

View from Top side (Scale 5:2)

Title:
Drill Drawing and Dimensions Drawn by:

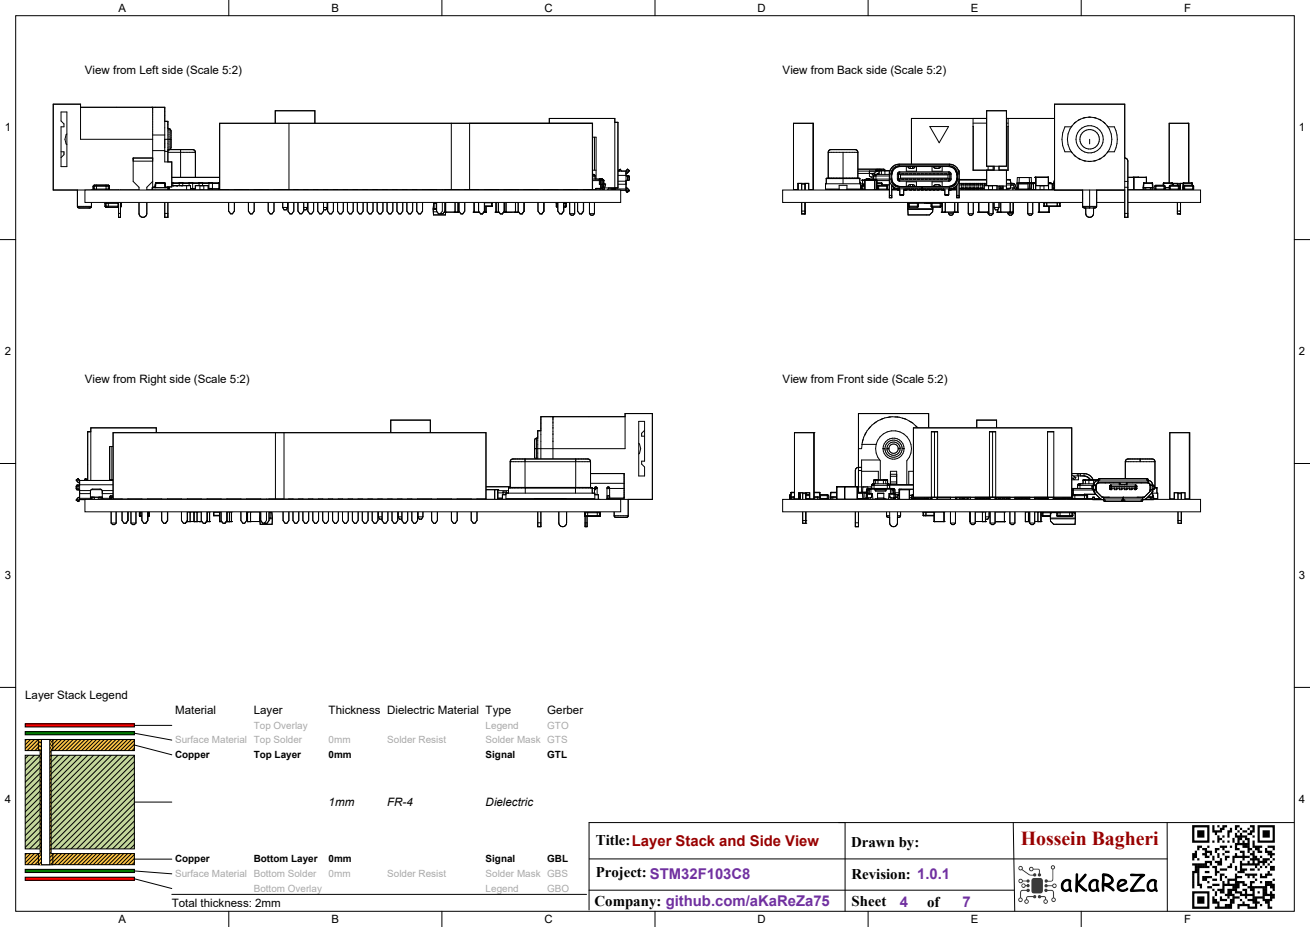
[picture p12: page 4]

View from Left side (Scale 5:2)

View from Back side (Scale 5:2)

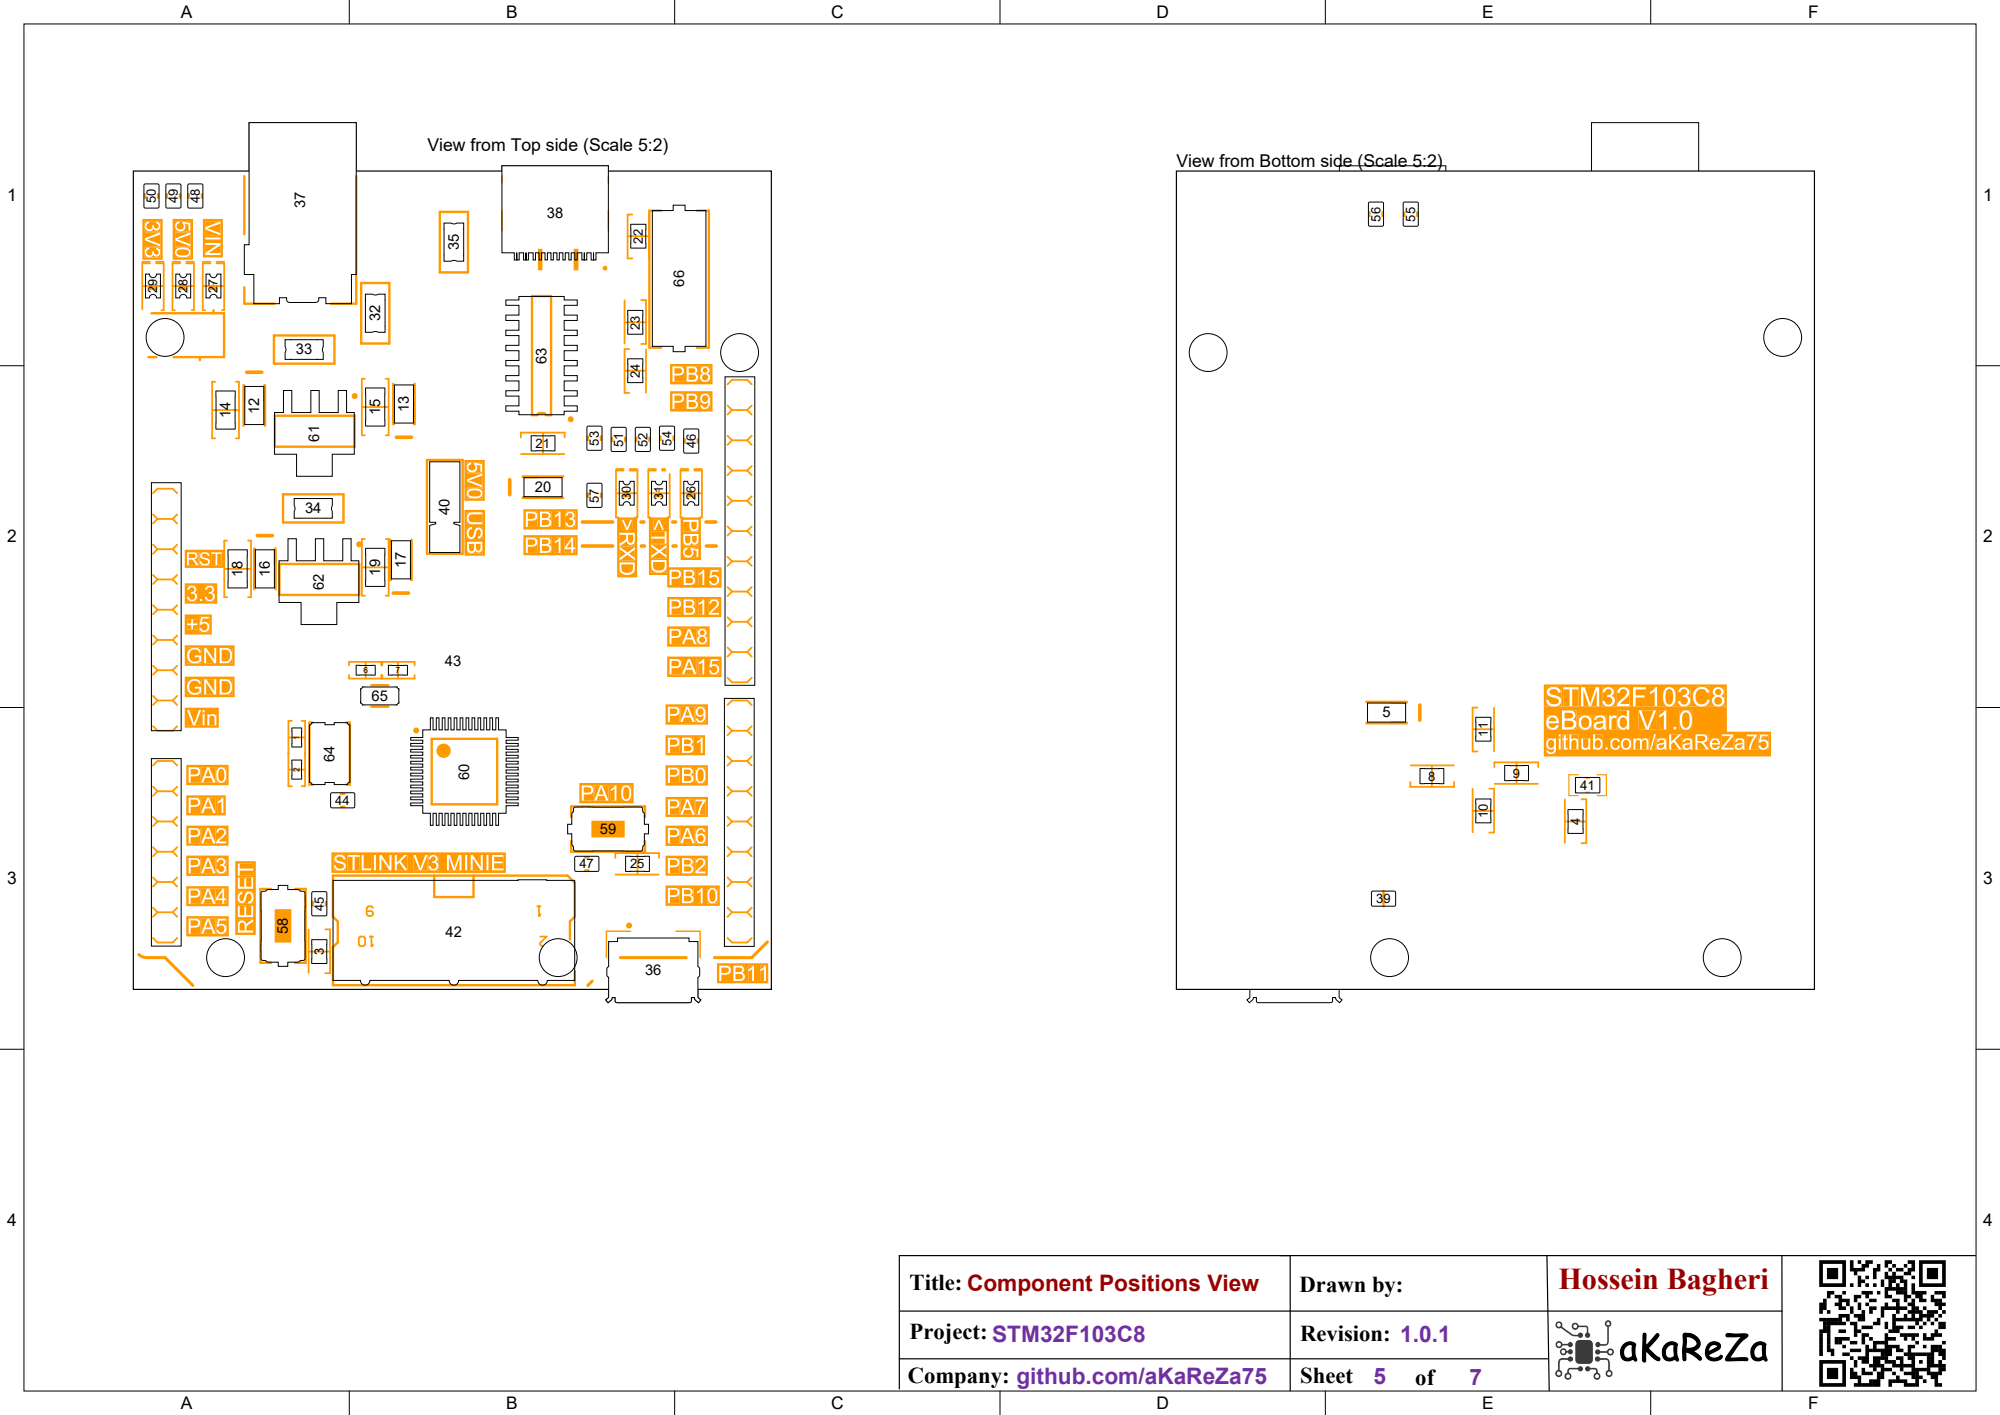
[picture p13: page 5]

View from Top side (Scale 5:2)

View from Bottom side (Scale 5:2)

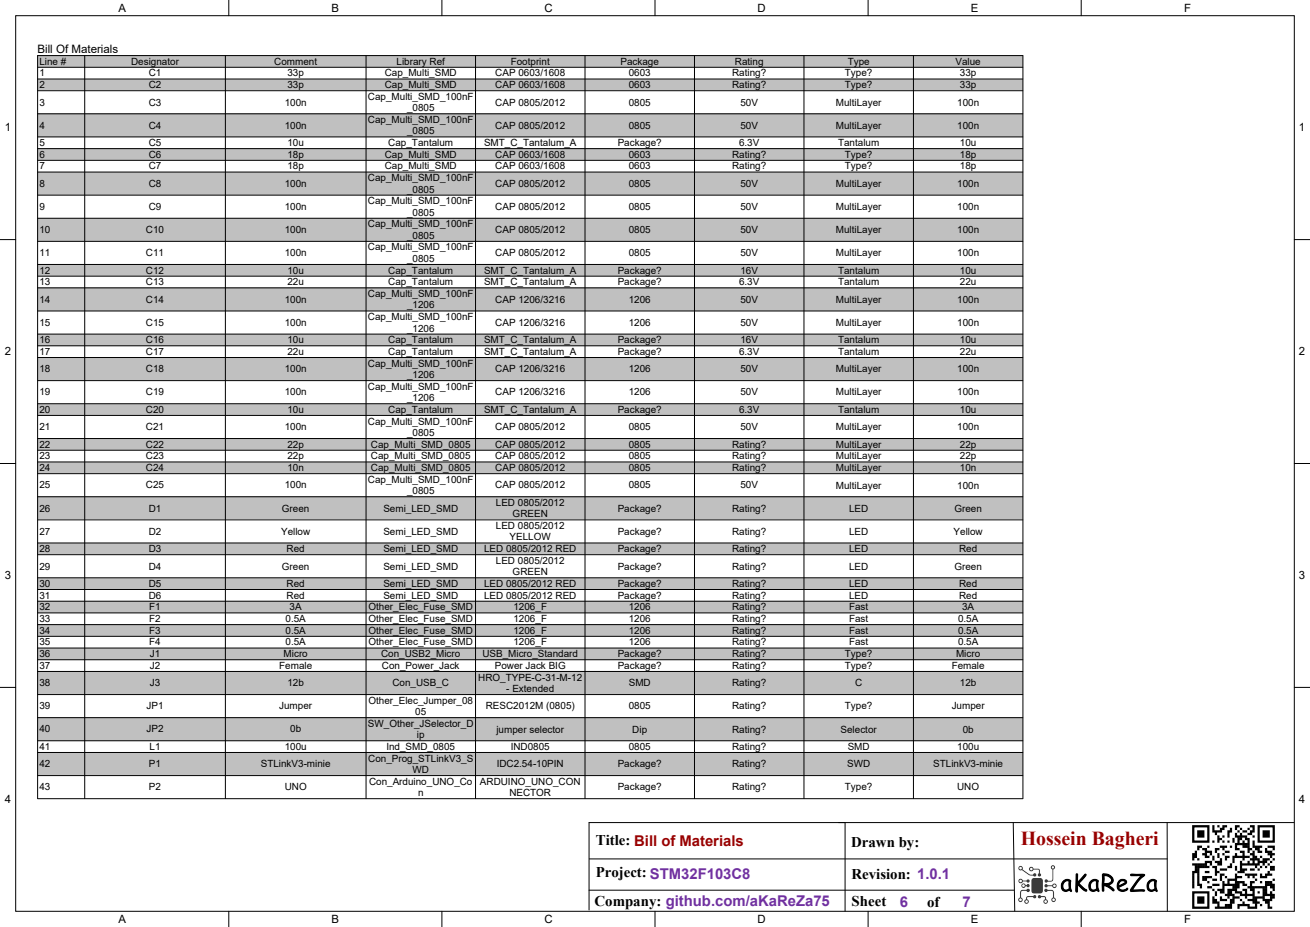
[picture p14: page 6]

Line # 123456789 | C3 | 100n | Cap_Multi_SMD_100nF _0805 | CAP 0805/2012 | 0805 | 50V | MultiLayer | 100n

Designator | Comment | Library Ref | Footprint | Package | Rating | Type | Value
C1 | 33p | Cap_Multi_SMD | CAP 0603/1608 | | Rating? | Type? | 33p
C2 | 33p | Cap_Multi_SMD | CAP 0603/1608 | 0603 | Rating? | Type? | 33p

C4 | 100n | Cap_Multi_SMD_100nF _0805 | CAP 0805/2012 | 0805 | 50V | MultiLayer | 100n

C5 | 10u | Cap_Tantalum | SMT_C_Tantalum_A | Package? | 6.3V | Tantalum | 10u
C6 | 18p | Cap_Multi_SMD | CAP 0603/1608 | 0603 | Rating? | Type? | 18p
C7 | 18p | Cap_Multi_SMD | CAP 0603/1608 | 0603 | Rating? | Type? | 18p
C8 | 100n | Cap_Multi_SMD_100nF _0805 | CAP 0805/2012 | 0805 | 50V | MultiLayer | 100n

C9 | 100n | Cap_Multi_SMD_100nF _0805 | CAP 0805/2012 | 0805 | 50V | MultiLayer | 100n

10 | C10 | 100n | Cap_Multi_SMD_100nF _0805 | CAP 0805/2012 | 0805 | 50V | MultiLayer | 100n

11 | C11 | 100n | Cap_Multi_SMD_100nF _0805 | CAP 0805/2012 | 0805 | 50V | MultiLayer | 100n

12 | C12 | 10u | Cap_Tantalum | SMT_C_Tantalum_A | Package? | 16V | Tantalum | 10u
13 | C13 | 22u | Cap_Tantalum | SMT_C_Tantalum_A | Package? | 6.3V | Tantalum | 22u
14 | C14 | 100n | Cap_Multi_SMD_100nF _1206 | CAP 1206/3216 | 1206 | 50V | MultiLayer | 100n

15 | C15 | 100n | Cap_Multi_SMD_100nF _1206 | CAP 1206/3216 | 1206 | 50V | MultiLayer | 100n

16 | C16 | 10u | Cap_Tantalum | SMT_C_Tantalum_A | Package? | 16V | Tantalum | 10u
17 | C17 | 22u | Cap_Tantalum | SMT_C_Tantalum_A | Package? | 6.3V | Tantalum | 22u
18 | C18 | 100n | Cap_Multi_SMD_100nF _1206 | CAP 1206/3216 | 1206 | 50V | MultiLayer | 100n

19 | C19 | 100n | Cap_Multi_SMD_100nF _1206 | CAP 1206/3216 | 1206 | 50V | MultiLayer | 100n

20 | C20 | 10u | Cap_Tantalum | SMT_C_Tantalum_A | Package? | 6.3V | Tantalum | 10u
21 | C21 | 100n | Cap_Multi_SMD_100nF _0805 | CAP 0805/2012 | 0805 | 50V | MultiLayer | 100n

22 | C22 | 22p | Cap_Multi_SMD_0805 | CAP 0805/2012 | 0805 | Rating? | MultiLayer | 22p
23 | C23 | 22p | Cap_Multi_SMD_0805 | CAP 0805/2012 | 0805 | Rating? | MultiLayer | 22p
24 | C24 | 10n | Cap_Multi_SMD_0805 | CAP 0805/2012 | 0805 | Rating? | MultiLayer | 10n
25 | C25 | 100n | Cap_Multi_SMD_100nF _0805 | CAP 0805/2012 | 0805 | 50V | MultiLayer | 100n

26 | D1 | Green | Semi_LED_SMD | LED 0805/2012 GREEN | Package? | Rating? | LED | Green

27 | D2 | Yellow | Semi_LED_SMD | LED 0805/2012 YELLOW | Package? | Rating? | LED | Yellow

28 | D3 | Red | Semi_LED_SMD | LED 0805/2012 RED | Package? | Rating? | LED | Red
29 | D4 | Green | Semi_LED_SMD | LED 0805/2012 GREEN | Package? | Rating? | LED | Green

30 | D5 | Red | Semi_LED_SMD | LED 0805/2012 RED | Package? | Rating? | LED | Red
31 | D6 | Red | Semi_LED_SMD | LED 0805/2012 RED | Package? | Rating? | LED | Red
32 | F1 | 3A | Other_Elec_Fuse_SMD | 1206_F | 1206 | Rating? | Fast | 3A
33 | F2 | 0.5A | Other_Elec_Fuse_SMD | 1206_F | 1206 | Rating? | Fast | 0.5A
34 | F3 | 0.5A | Other_Elec_Fuse_SMD | 1206_F | 1206 | Rating? | Fast | 0.5A
35 | F4 | 0.5A | Other_Elec_Fuse_SMD | 1206_F | 1206 | Rating? | Fast | 0.5A
36 | J1 | Micro | Con_USB2_Micro | USB_Micro_Standard | Package? | Rating? | Type? | Micro
37 | J2 | Female | Con_Power_Jack | Power Jack BIG | Package? | Rating? | Type? C | Female
38 | J3 | 12b | Con_USB_C | HRO_TYPE-C-31-M-12 - Extended | SMD | Rating? | | 12b

39 | JP1 | Jumper | Other_Elec_Jumper_08 05 | RESC2012M (0805) | 0805 | Rating? | Type? | Jumper

40 | JP2 | 0b | SW_Other_JSelector_D ip | jumper selector | Dip | Rating? | Selector | 0b

41 | L1 | 100u | Ind_SMD_0805 | IND0805 | 0805 | Rating? | SMD | 100u
42 | P1 | STLinkV3-minie | Con_Prog_STLinkV3_S WD | IDC2.54-10PIN | Package? | Rating? | SWD | STLinkV3-minie

43 | P2 | UNO | Con_Arduino_UNO_Co n | ARDUINO_UNO_CON NECTOR | Package? | Rating? | Type? | UNO

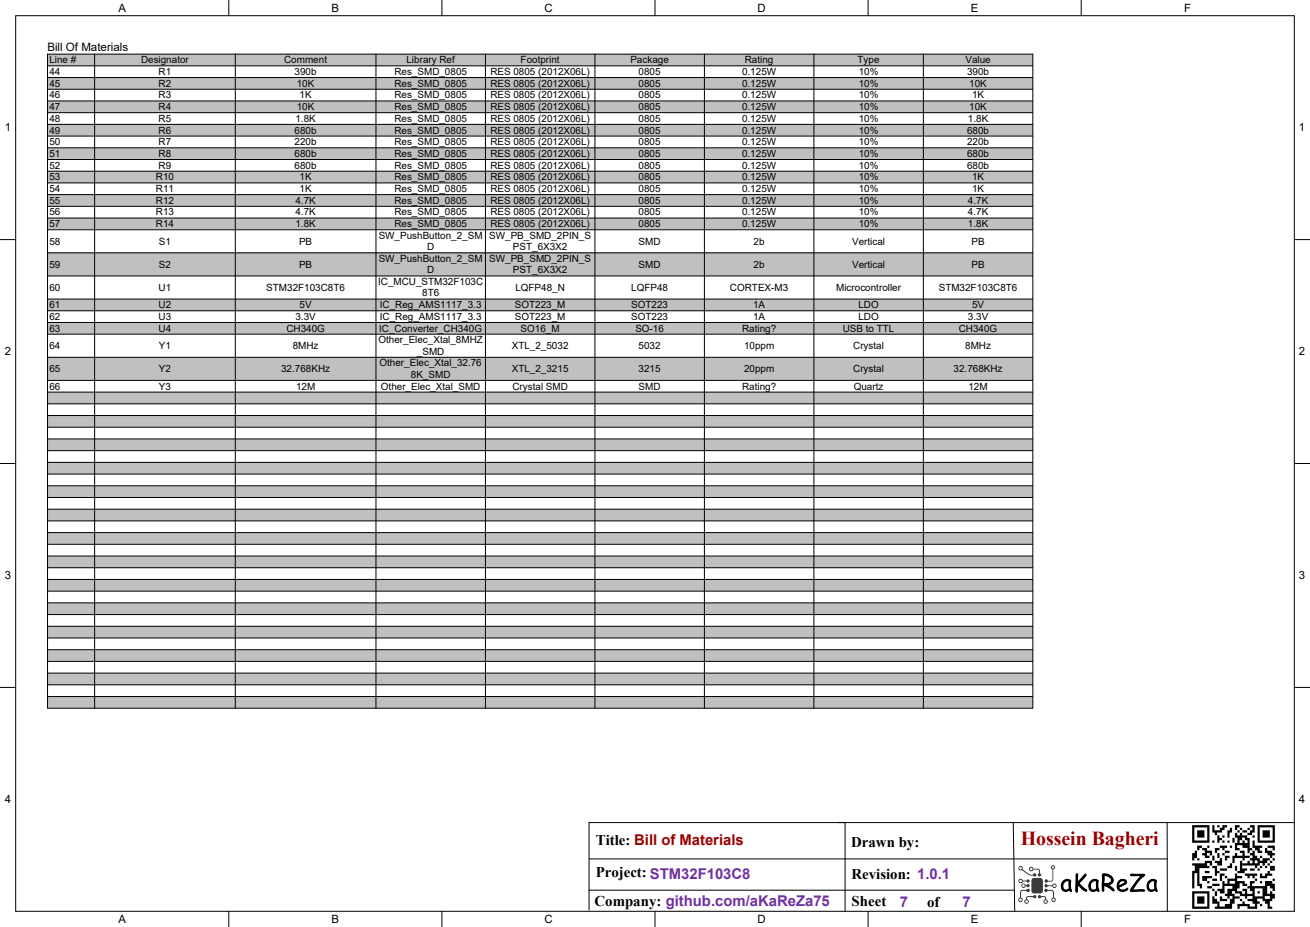
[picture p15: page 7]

Line # | Designator | Comment | Library Ref | Footprint | Package | Rating | Type | Value

R1 | 390b | Res_SMD_0805 | RES 0805 (2012X06L) | | 0.125W | 10% | 390b
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

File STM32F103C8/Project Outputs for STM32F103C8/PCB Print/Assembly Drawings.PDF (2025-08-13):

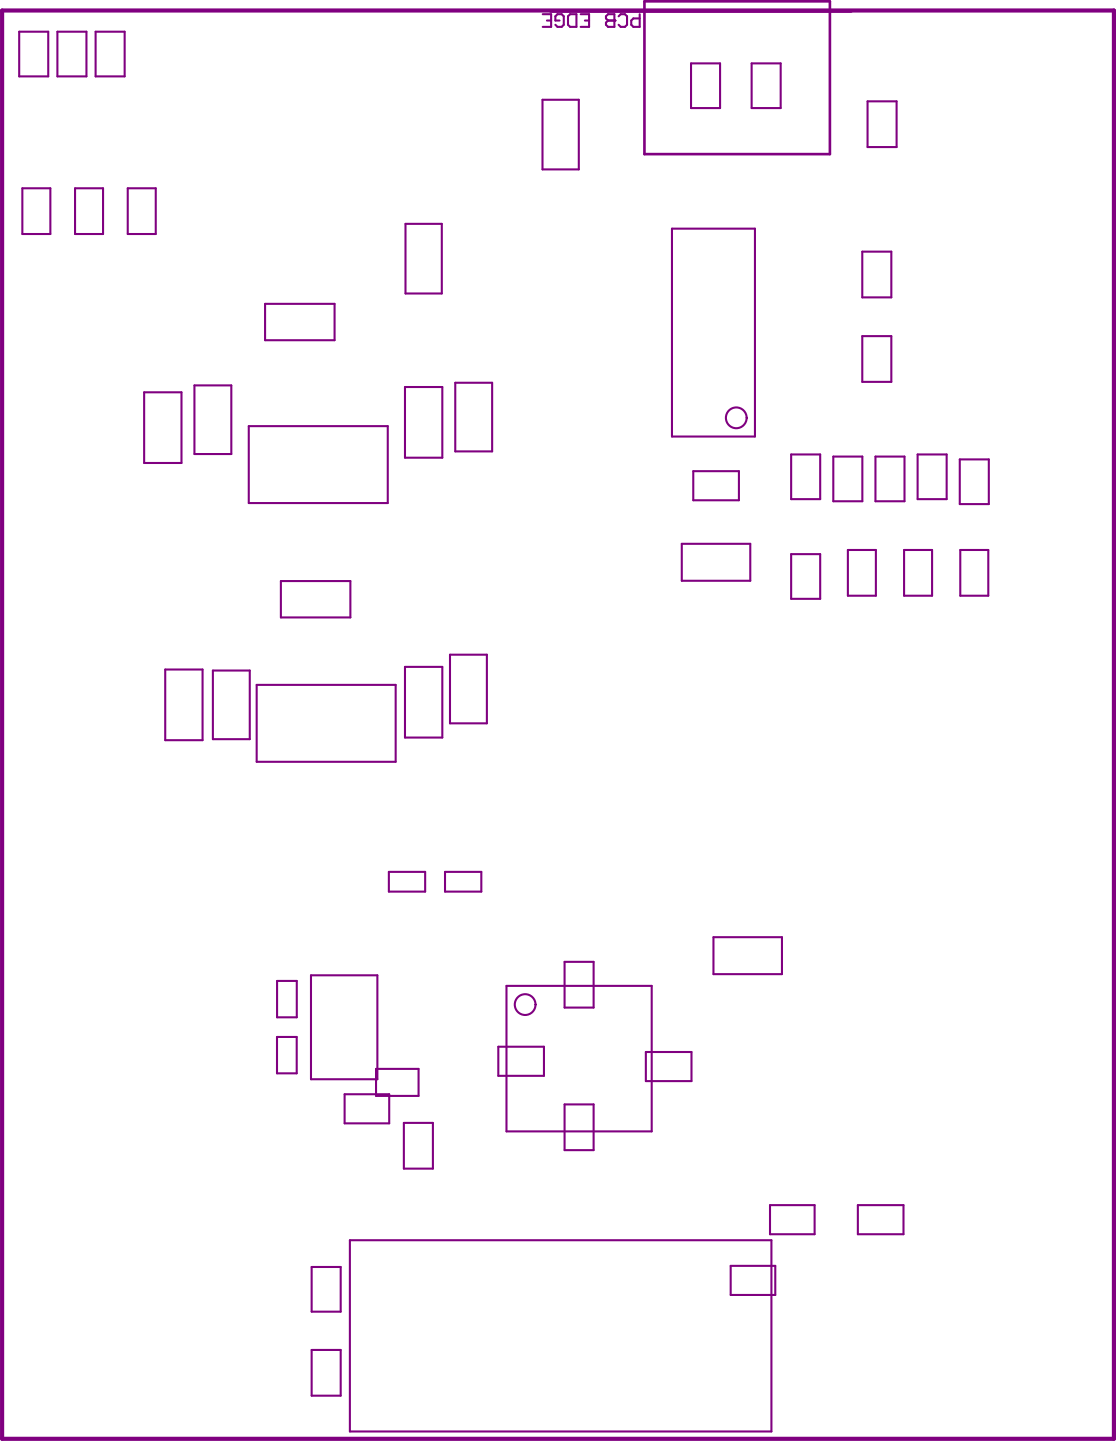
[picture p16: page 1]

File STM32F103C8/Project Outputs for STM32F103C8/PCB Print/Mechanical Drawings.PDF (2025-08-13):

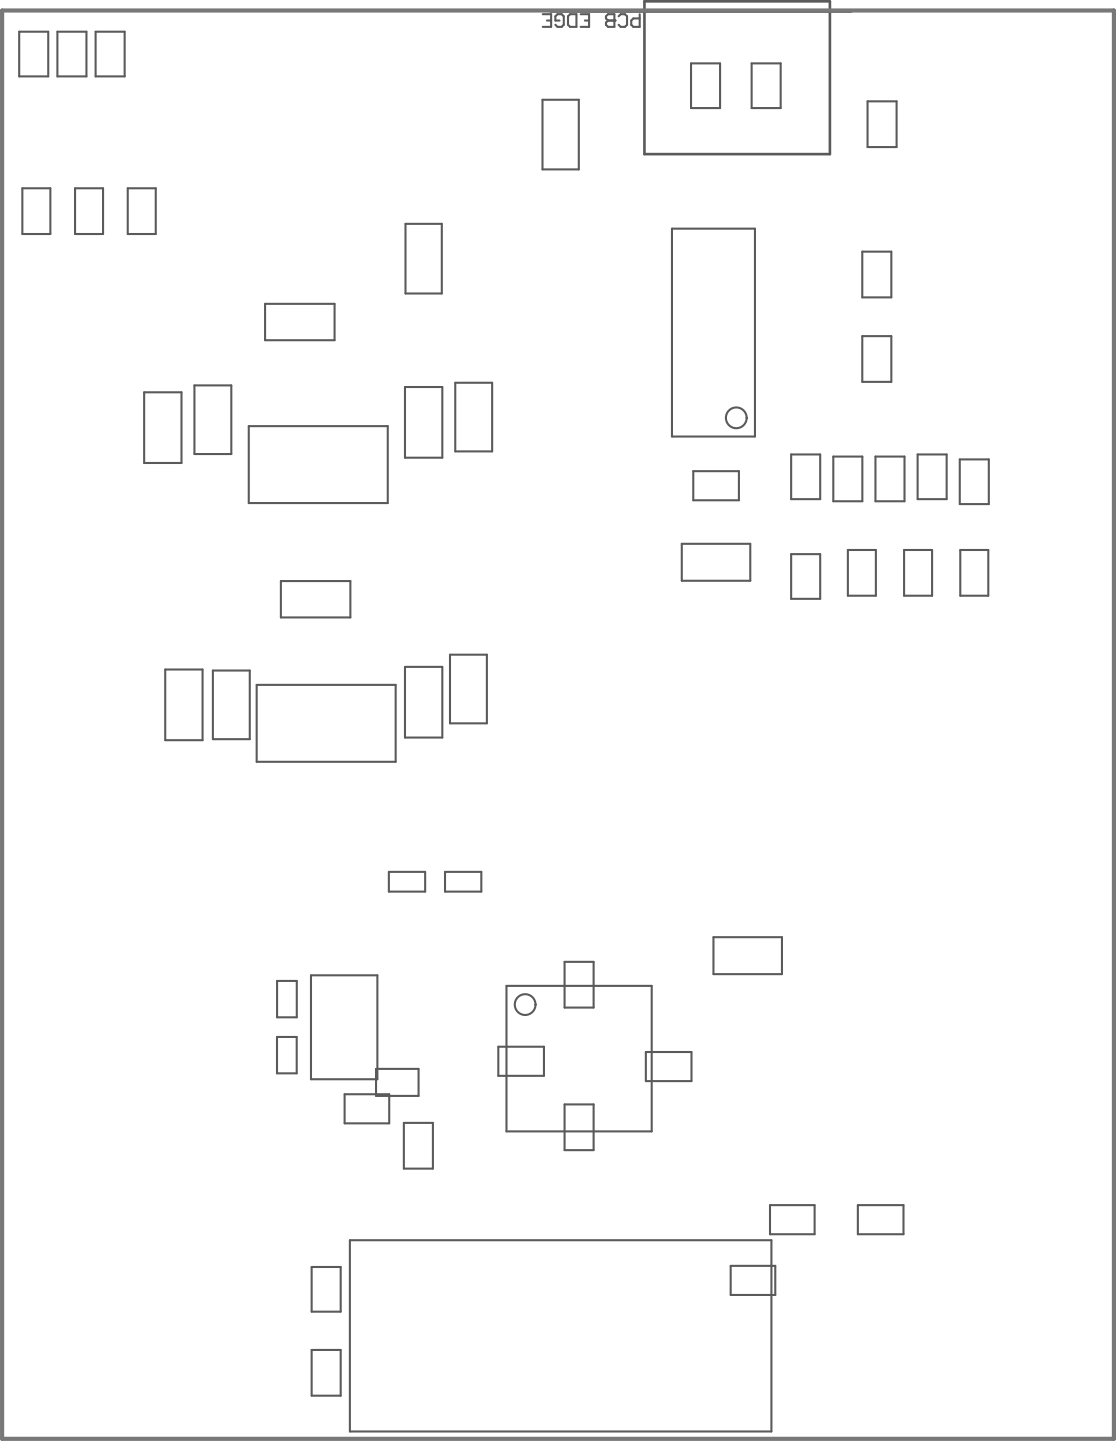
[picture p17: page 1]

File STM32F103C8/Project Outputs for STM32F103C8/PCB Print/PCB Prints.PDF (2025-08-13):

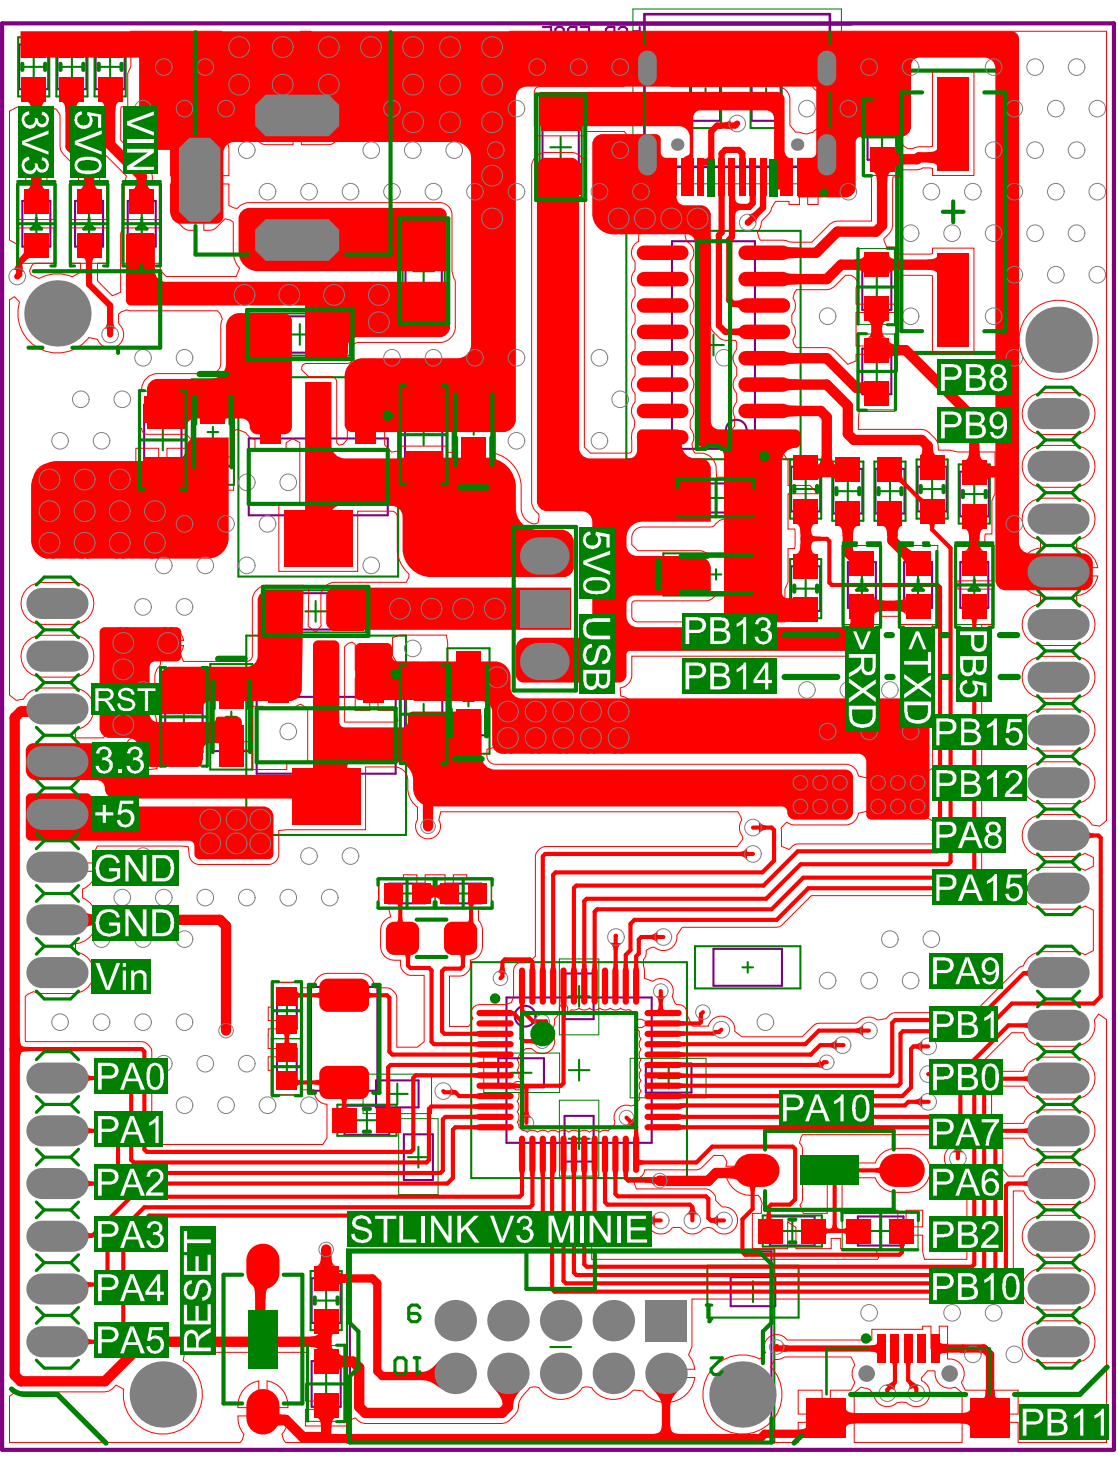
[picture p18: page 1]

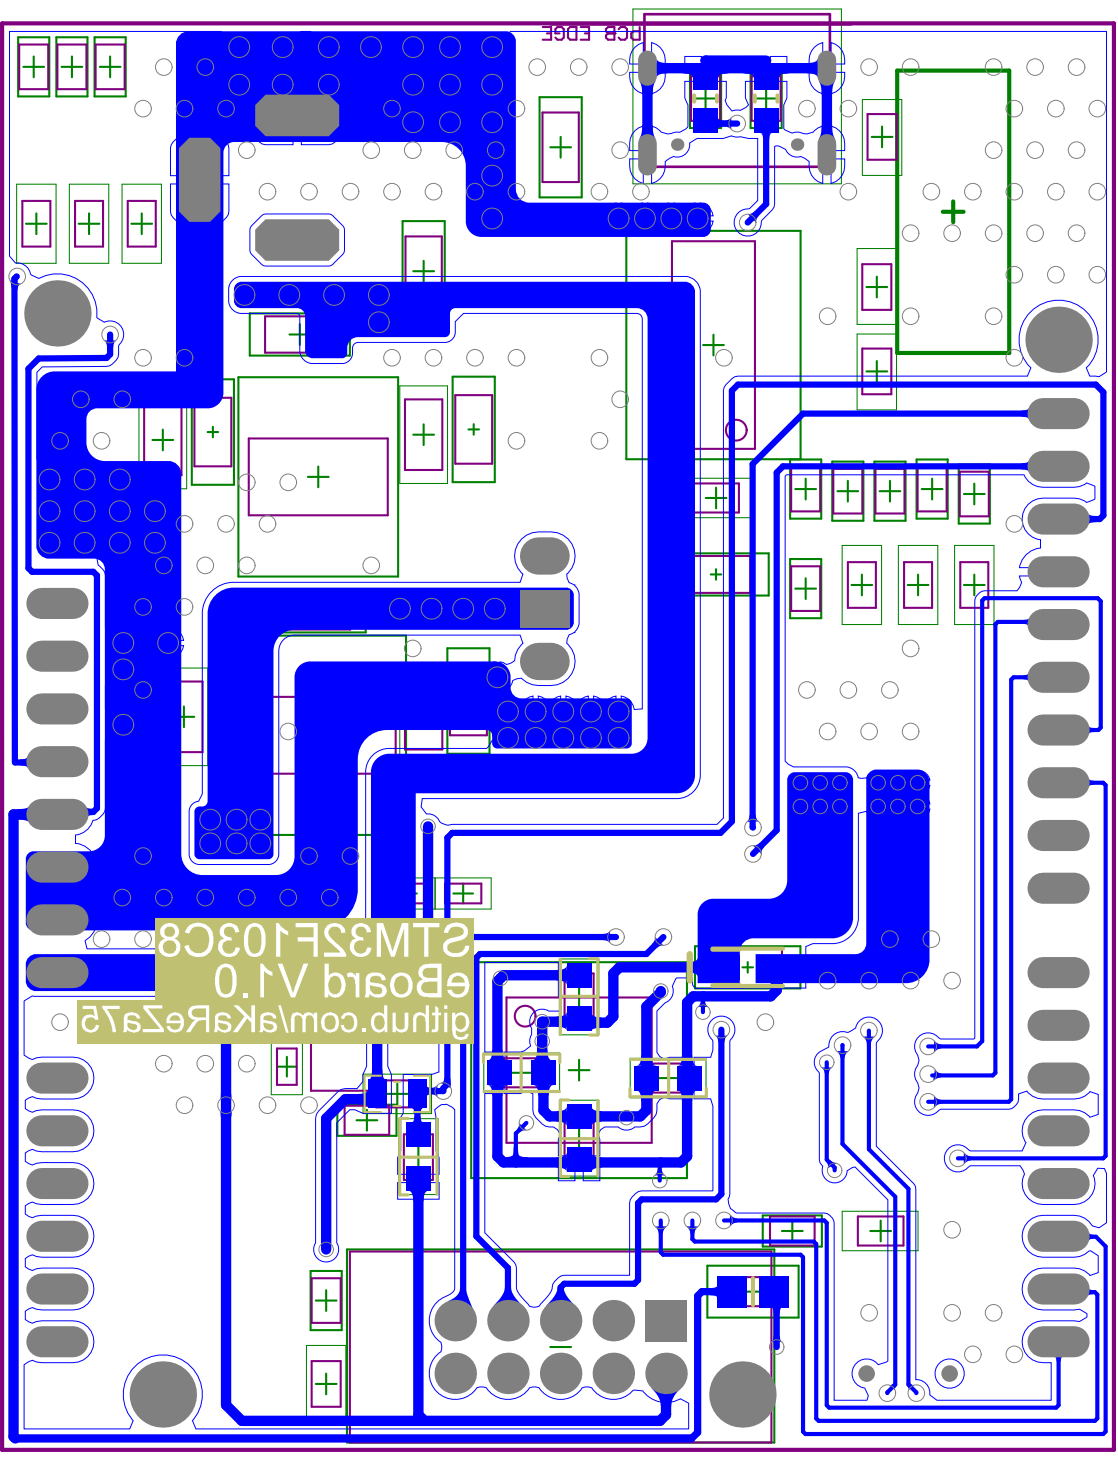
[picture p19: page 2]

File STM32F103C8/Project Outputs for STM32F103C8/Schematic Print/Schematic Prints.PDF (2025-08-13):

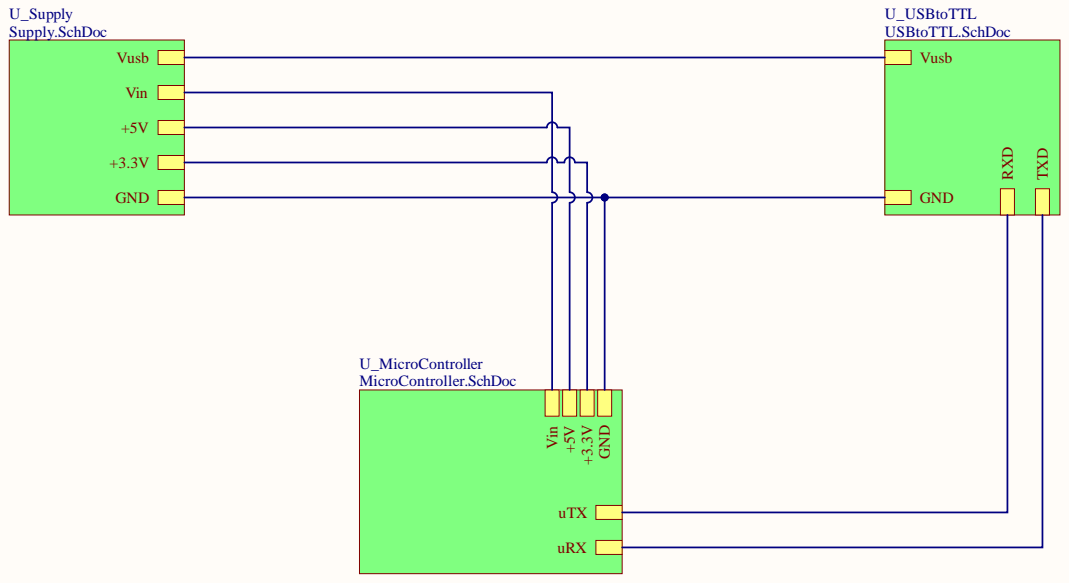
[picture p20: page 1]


3 6
4 8




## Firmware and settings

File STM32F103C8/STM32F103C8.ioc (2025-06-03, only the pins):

Mcu.UserName=STM32F103C8Tx
PA0-WKUP.GPIO_Label=A0
PA0-WKUP.Signal=ADCx_IN0
PA1.GPIO_Label=A1
PA1.Signal=ADCx_IN1
PA10.GPIO_Label=KEY
PA10.Signal=GPIO_Input
PA11.Signal=USB_DM
PA12.Signal=USB_DP
PA13.Signal=SYS_JTMS-SWDIO
PA14.Signal=SYS_JTCK-SWCLK
PA15.GPIO_Label=D8
PA15.Signal=S_TIM2_CH1_ETR
PA2.GPIO_Label=A2
PA2.Signal=ADCx_IN2
PA3.GPIO_Label=A3
PA3.Signal=ADCx_IN3
PA4.GPIO_Label=A4
PA4.Signal=ADCx_IN4
PA5.GPIO_Label=A5
PA5.Signal=ADCx_IN5
PA6.GPIO_Label=PWM-D3
PA6.Signal=S_TIM3_CH1
PA7.GPIO_Label=D4
PA7.Signal=S_TIM3_CH2
PA8.GPIO_Label=PWM-D9
PA8.Signal=S_TIM1_CH1
PA9.GPIO_Label=D7
PA9.Signal=S_TIM1_CH2
PB0.GPIO_Label=PWM-D5
PB0.Signal=S_TIM3_CH3
PB1.GPIO_Label=PWM-D6
PB1.Signal=S_TIM3_CH4
PB10.GPIO_Label=TX_D1
PB10.Signal=USART3_TX
PB11.GPIO_Label=RX_D0
PB11.Signal=USART3_RX
PB12.GPIO_Label=NSS_D10
PB12.Signal=SPI2_NSS
PB13.GPIO_Label=SCK_D13
PB13.Signal=SPI2_SCK
PB14.GPIO_Label=MISO_D12
PB14.Signal=SPI2_MISO
PB15.GPIO_Label=MOSI_D11
PB15.Signal=SPI2_MOSI
PB2.GPIO_Label=D2
PB2.Signal=GPIO_Output
PB3.Signal=SYS_JTDO-TRACESWO
PB5.GPIO_Label=GPIO_LED
PB5.Signal=GPIO_Output
PB6.Signal=USART1_TX
PB7.Signal=USART1_RX
PB8.GPIO_Label=SCL
PB8.Signal=I2C1_SCL
PB9.GPIO_Label=SDA
PB9.Signal=I2C1_SDA
PC14-OSC32_IN.Signal=RCC_OSC32_IN
PC15-OSC32_OUT.Signal=RCC_OSC32_OUT
PD0-OSC_IN.Signal=RCC_OSC_IN
PD1-OSC_OUT.Signal=RCC_OSC_OUT

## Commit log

2025-06-03 Complete Project!
    [Main.SchDoc, MicroController.SchDoc, PCB.PcbDoc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]
2025-06-03 add STM32 Pic
2025-06-10 improve routing and update documents
    [PCB_Copper_Signal_Bot.gbr, PCB_Copper_Signal_Top.gbr, PCB_Drawing_1.gbr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]
2025-06-17 Update Pa9 net name
    [MicroController.SchDoc]
2025-06-18 add ShopimgLink Md File and Update Value of some components
    [MicroController.SchDoc, USBtoTTL.SchDoc]
2025-07-24 add BoasTools
    [STM32F103C8.PrjPcb]
2025-07-24 add STlink Interface
    [Interface.PrjPcb, PCB.PcbDoc, Sheet1.SchDoc]
2025-08-13 Resolve issues of v1.0
    [PCB.PcbDoc, PCB.step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]
2025-08-13 resolve errors
    [Interface.PrjPcb, PCB.PcbDoc, Sheet1.SchDoc]
